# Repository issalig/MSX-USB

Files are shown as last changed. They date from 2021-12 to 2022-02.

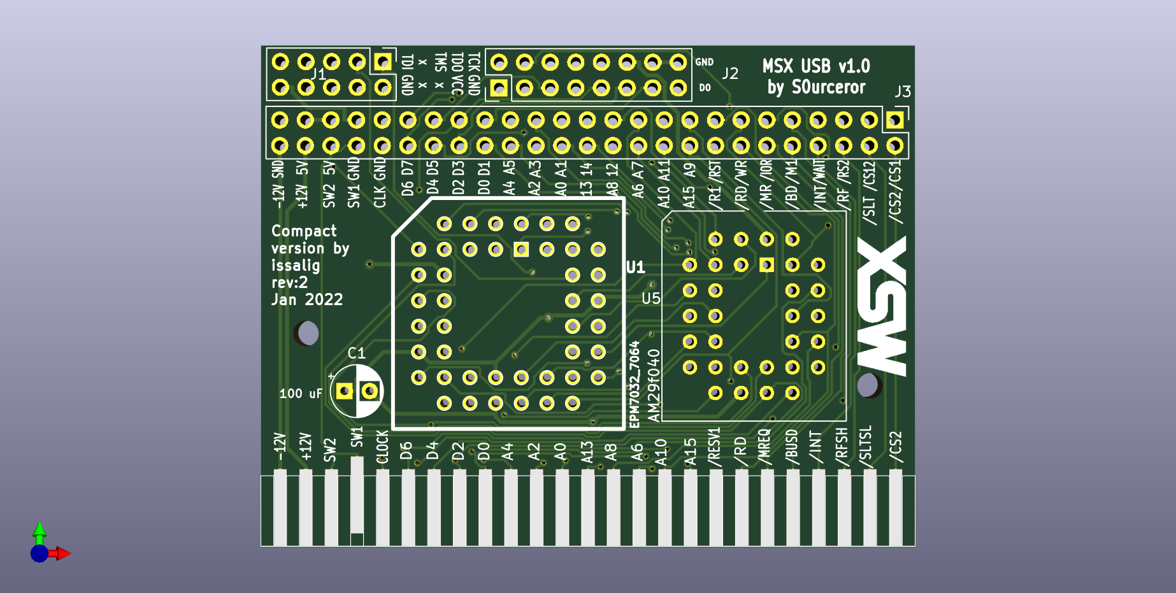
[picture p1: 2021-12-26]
hardware/kicad-cpld-mini-v2/MSX USB Drive.png

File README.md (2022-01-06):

# MSX-USB
## My fork and DIY guide
My fork provides a minified version of the pcb with PLC sockets and a header expansion as well as detailed building guide. All the other things are the same as original S0urceror version (https://github.com/S0urceror/MSX-USB) and I send him lots of thanks for sharing his knowledge.

As I built the cartridge from the scratch I will tell you some of the problems I faced and happily solved out.

### Step 0: Make a PCB
When I saw original S0urceror design I thought that maybe using PLC sockets could make the pcb smaller, then I tried to shrink everything into the minimum space with the maximum capabilities and that's why I added a expansion header. I am using https://www.kicad.org/ for the PCB layout and https://freerouting.org/ for the routing. I find freerouting extremely useful since there are a lot of connections and a small place to do the job. Sometines freerouting does not find the solution and you need to finish it manually. If this happens you can also lower clearance matrix values down to 125-150. Also using freerouting allows you to change the location of components without the need to re-route everything again.

Last version of the pcb is kicad-cpld-mini-v2 (ch376 is in front but still *untested*) and kicad-cpld-mini (ch376 is in the back side and *tested ok*).  Of course if you are satisfied with my design just can just use the files provided. Otherwise you can improve the design and share it.

### Step 1: Program CPLD
You will need the obsolete part EPM7064SLC44, the important part here is **SLC**, EPM7064SLC44-10 is also valid. You can get them from ali and other places but as they are refurbished/recovered from dumpsters expect to have only 50% working, so order double. Here is a possible link https://aliexpress.com/item/1005001512009032.html but there is a myriad of sellers.
Then, you will need a programmer such as USB blaster. I got this one https://aliexpress.com/item/1005002674193901.html
Next, you have to download Quartus software version **13.0sp1**, as newer versions do not support EPM7064. Go to https://fpgasoftware.intel.com/?edition=lite and proceed with the download and installation.

If you are in linux like me you will  need to add the this rules to file /etc/udev/rules.d/37-usbblaster.rules
```
SUBSYSTEM=="usb", ATTRS{idVendor}=="09fb", ATTRS{idProduct}=="6001", GROUP="plugdev", MODE="0666", SYMLINK+="usbblaster" 
```
and then restart the service
```
sudo service udev restart 
```

Connect the programmer to the board and also **power the board externally with 5V**, you can do it using the expansion header or CH3786 header. Find the pins VCC and GND and you are done. Failing to do so it will result in an JTAG read error.

Next, we check your connection and if everything went ok you will see this message.
```
$ ./quartus_pgm --auto
Info (213045): Using programming cable "USB-Blaster [3-1]"
1) USB-Blaster [3-1]
  070640DD   EPM7064S

Info: Quartus II 32-bit Programmer was successful. 0 errors, 0 warnings
    Info: Peak virtual memory: 127 megabytes
    Info: Processing ended: Sat Dec 18 10:16:56 2021
    Info: Elapsed time: 00:00:00
    Info: Total CPU time (on all processors): 00:00:00
```

And it has arrived the amazing moment where you are going to program it (you can do it with the command line *quartus_pgm* or with the GUI tool *quartus*)
with the following file https://github.com/S0urceror/MSX-USB/blob/master/hardware/quartus/output_files/MSXUSB.pof
```
./quartus_pgm -m jtag -o "p;./MSXUSB.pof"
```

In case the devices still shows JTAG communication error, keep calm and go to the next step.

### Step 1b. Recovering deaf JTAG units
It happens that some of the refurbished units come with programs that used JTAG pins for I/O and they are not able to be used for JTAG. I threw some of them to the bin until I discovered a recovery process (https://www.eevblog.com/forum/fpga/atmel-atf150x-cpld-and-wincupl/msg3162224/#msg3162224).
- Apply 12V to CPLD pin OE1 (44) with a 2k2 resistor for a minute or so. In my pcb you can access OE1 pin on header pin 15 (RST).
- Disconnect 12V, connect 5V and try to program it.
- Hopefully some CPLD's are working now! 

### Step 1c. Use an still in production CPLD, use a ATF1504AS
As seen in https://www.eevblog.com/forum/fpga/atmel-atf150x-cpld-and-wincupl/msg3113922/#msg3113922 ATF1504AS is pin compatible to EPM7064 and it is a valid replacement for EPM7064.
The changes are not that big: we will need to convert .pof into .jed and then into .svf.

I compiled the following info from different sources https://github.com/marqs85/snes_dejitter/blob/master/README.md, https://github.com/SukkoPera/OpenAmiga500FastRamExpansion/blob/master/firmware/README.md and https://www.hackup.net/2020/01/erasing-and-programming-the-atf1504-cpld/

All the resources for ATMEL CPLDS can be found at https://www.microchip.com/en-us/products/fpgas-and-plds/spld-cplds/pld-design-resources

First we need to download pof2jef from http://ww1.microchip.com/downloads/archive/pof2jed.zip
Then in winpof2jed.exe (yes it works with wine in linux :))
```
1. Select .pof file from previous step as input file
2. Select 1504AS as device
3. Change the following options:
  * Reduce MC power -> On
  * Open Collector -> Off
  * JTAG mode -> On
  * Slew rate -> Slow
4. Click "Run"
```

The important thing here is JTAG Mode **ON**, if you are wrong you will block JTAG but don't panic, we already know that applying 12V it will be enabled again.

Once we have the .jed file it is time to generate svf with ATMISP that you can download it from http://ww1.microchip.com/downloads/en/DeviceDoc/ATMISP7.zip. Then, you should follow these steps.

```
1. Create a new device chain via File->New
2. Set number of devices to 1
3. Set device to ATF1504AS
4. Set JTAG instruction to "Program/Verify"
5. Select .jed file from previous step as JEDEC file
6. Name your svf file
7. Click "OK"
8. Tick "Write SVF file" and click "Run"
```

We are almost there. We just need to flash it with openocd

But first we need the config file for usbblaster and you can save it as altera-usb-blaster.cfg
```
#
# Altera USB-Blaster
#
# http://www.altera.com/literature/ug/ug_usb_blstr.pdf
#

interface usb_blaster
usb_blaster_lowlevel_driver ftdi
# These are already the defaults.
# usb_blaster_vid_pid 0x09FB 0x6001
# usb_blaster_device_desc "USB-Blaster"
adapter_khz 3000
```

And this is the magical line that will flash your CPLD (Do not forget to power usbblaster with external 5V)

```
 openocd -f altera-usb-blaster.cfg -c "adapter_khz 400" -c "transport select jtag" -c "jtag newtap ATF1504AS tap -irlen 3 -expected-id 0x0150403f" -c init -c "svf msxusb.svf" -c "sleep 200" -c shutdown
 ```
 
If everything went ok you will see something ending like this

```
Time used: 0m12s613ms 
svf file programmed successfully for 3299 commands with 0 errors
shutdown command invoked

```

### Step 2. Flash memory
Recommended memory chips is SST39SF040 (512kb) but I also managed to make it work with SST39SF020 (256kb). Then, you will need a programmer such as TL866 II https://aliexpress.com/item/33000308958.html and the file we will write is located at https://github.com/S0urceror/MSX-USB/blob/master/drivers/NextorUsbHost/dist/nextor.rom

If you prefer to use a command line tool I suggest you minipro https://gitlab.com/DavidGriffith/minipro

```
$ ./minipro --device SST39SF040@PLCC32 --write nextor.rom -s
Found TL866II+ 04.2.126 (0x27e)
Warning: Firmware is newer than expected.
  Expected  04.2.124 (0x27c)
  Found     04.2.126 (0x27e)
Chip ID OK: 0xBFB7
Warning: Incorrect file size: 131072 (needed 524288)
Erasing... 0.40Sec OK
Writing Code...  26.38Sec  OK
Reading Code...  4.00Sec  OK
Verification OK

```

### Step 3. Select a valid USB drive
Not all USB drives will work :(, I have detected that the ones with the following EnpointAddress values usually work. It will probably work if you have the values shown below. If you find other values, please report.
```
lsusb -v | grep bEndpointAddress
...
bEndpointAddress 0x01 EP 1 OUT
bEndpointAddress 0x82 EP 2 IN 
```

### Step 4. Prepare a disk
Once we are here, all the hardware requirements are fulfilled, yes, you can go for a beer now!
It is only a matter of creating a disk image with the system files provided at https://github.com/S0urceror/MSX-USB/tree/master/software/dist

- If you have a MSX1 (i.e. VG8020, ...) you will be limited to 720kb disks and FAT12. Do not complain, do you still prefer a slow datacorder?
To create a MSX disk image I use dsktool from https://github.com/nataliapc/MSX_devs/tree/master/dsktool

I also provide linux and windows version of dsktool in order to make it easier, you can get them at https://github.com/issalig/MSX-USB/tree/master/software/utils
```
#create disk
dsktool c MYDISK.DSK
#add system files
dsktool a MYDISK.DSK COMMAND.COM MSXDOS.SYS
#add other files
dsktool a MYDISK.DSK MYGAME.COM
```
In case you prefer a GUI program you can also use DiskMgr http://www.lexlechz.at/en/software/DiskMgr.html

Next, flash it. **Warning: check if your device is /dev/sda** or you will destroy something. If you are a windows user maybe Rufus can write the image, if it works, please report it. 

```
sudo dd if=MYDISK.DSK of=/dev/sda
```

- If you are a lucky MSX2 owner you will need a FAT16 partition of 16Mb with COMMAND2.COM and NEXTOR.SYS.

In Linux I have created an image available at https://github.com/issalig/MSX-USB/blob/master/software/utils/msx2.zip. You can do it with the following commands.
```
#create a 16 Mb disk and format it to FAT16
sudo  dd if=/dev/zero of=msx2.dsk bs=1024 count=16k
sudo mkfs.fat -F 16 msx2.dsk

#mount it
mkdir 16mb 
sudo mount -o loop msx2.dsk 16mb/

#copy all the stuff
sudo cp COMMAND2.COM NEXTOR.SYS 16mb

#unmount it and flash it
sudo umount 16mb
sudo dd if=msx2.dsk of=/dev/sda bs=16M
```
Unplug the stick from the computer, plug it in the msxusb, switch on the MSX and you are in. **Enjoy!**

As usual report how is it done with windows (maybe mini partition tool can help but I have never tried it).

## Some history
In the 80's the MSX standard was created by Kazuhiko Nishi. He envisioned a simple yet powerful home computer based on standard hardware, software (BIOS/MSX DOS) and connectivity. From 1983 to 1990 manufacturers, like Philips, Sony, Yamaha, Sharp, Canon and many more, made computers according to this standard.

Because of the fact that extensibility was part of the standard people could design cartridges that would add synthesizer sound, memory, modems, rom-based games, or combinations of the above.

Cartridges were connected via a standard 50pin connector that remained the same accross 4 generations of MSX (1/2/2+/TurboR). BIOS and MSX-DOS were designed in a way to discover these via rom-based drivers, software hooks, extended bios.

Standardisation offers a big advantage because everything that adheres to the standard can connect to it.

## USB
USB was designed in the 90's to do something similar. To standardize the connection of peripherals to personal computers, both to communicate with and to supply electric power. It has now largely replaced interfaces such as serial ports and parallel ports, and has become commonplace on a wide range of devices. Like USB flash drives, keyboards, mice, wifi, serial, camera's, etc.

What if the MSX would have an USB connection? And if the BIOS/MSX DOS would automatically recognize devices connected to it?

## Meet MSX-USB
Inspired by the work of Xavirompe and his [RookieDrive](http://rookiedrive.com/en/) I set out to do exactly this. And since I'm a big believer of open standards and open source I'm opening up my work to everyone.

On this GitHub page you can find:
* Schematics (KiCAD), that interfaces a cheap USB CH376s board to the MSX cartridge port.
* Drivers, currently Flash drives on Nextor and HID keyboards are supported.
* Debugging tools, to connect a test board to your PC/MAC and assist in debugging.

On my GitHub I also have forks of OpenMSX and CocoaMSX that either emulate or connect to a test board via serial to assist in development and debugging.

## Schematics
This connects the CH376s board you can find on eBay or AliExpress for around 4 Euro to the MSX. 

Circuitry is added to correctly handle the _BUSDIR signal. Make sure you select parallel by setting the jumper on the CH376s board correctly.

The CH376s board will be visible on port 10h and 11h on the MSX. Port 11h is the command port and 10h is the data port. Specifics on how to program for the CH376s are scattered around the Internet:
* https://www.mpja.com/download/ch376ds1.pdf
* https://arduinobasics.blogspot.com/2015/05/ch376s-usb-readwrite-module.html

Most information is available on how to use the higher-order API for flash drives. 

If you want to use other USB devices you have to go low-level. As it turns out Konamiman already did some work there and after some researching I got USB HID Keyboards, Ethernet, Serial working as well. Check out my source-code or these great pages for more information:
* http://www.usbmadesimple.co.uk/index.html
* https://www.beyondlogic.org/usbnutshell/usb1.shtml

## UNAPI USB
I wrote a UNAPI USB specification and implemented the Usb Host driver according to this. The next version of this Host driver will also implement the Usb Hub specification and enumerate and initialise all devices connected.

## USB HID Keyboard
The Usb Keyboard driver connects to Unapi Usb driver and hooks itself to H.CHGE. From that moment on it replaces your trusted MSX keyboard by a shiny new USB Keyboard. Or a wireless one if you have inserted the appropriate Logitech receiver.

## USB CDC ECM Ethernet
The USB CDC ECM Ethernet driver is finished. It uses the Unapi USB and conforms to the Unapi Ethernet standard. Internestor Lite can now connect and use your USB Ethernet device. Please note that currently we only support USB CDC ECM. Make sure your Ethernet device supports this.

All USB Ethernet devices built around the **RTL8153** chipset support USB CDC ECM. They usually cost around 20 euro.

## USB Storage
A low level USB driver is created to connect to storage devices like thumb drives, portable hard disks, etc. 

## USB Hub
The USB Hub driver will interrogate an USB Hub and all devices connected to it.

# Installation instructions
Check [this page](INSTALL.md) for installation instructions and links to the various binaries that have been developed.

# Build your own (DIY)
Check [this page](DIY.md) for information on how to make the PCB, program the CPLD device, flash the ROM, etc.

# Collaboration
Do you want to help with the development of MSX USB? Write drivers for other devices? Or contribute in other ways?

Please drop me line on sourceror at neximus.nl or meet me on the msx.org forum.

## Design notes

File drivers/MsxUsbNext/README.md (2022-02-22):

## Usage
This is a Nextor driver programmed in C. It mounts the USB disk connected to the MSXUSB cartridge. Other devices and USB hubs are not supported by this driver.

### Disk formats supported
1. FAT32
    - Format in Windows, MacOS, Linux with master boot record. 
    - Place .DSK floppy images in the root folder or subfolders. 
    - Select the right DSK file during MSX boot.
2. FAT16
    - Format in Windows, MacOS, Linux with master boot record. 
    - Place .DSK floppy images in the root folder or subfolders. 
    - Select the right DSK file during MSX boot. 
    - **NEXTOR can also mount the whole USB drive in FAT16 mode**
3. FAT12
    - Format in MacOS, Linux or by DD-ing a DSK file to the USB drive. 
    - You will waste a lot of space because now the USB drive can only contain 720kb.

### MSX compatibility
On MSX 1 you can only mount FAT12 720kb DSK images. On MSX 2 and higher you can mount FAT16 DSK images of various sizes or the whole USB disk when formatted in FAT16.

### AUTOEXEC.DSK
Place a disk image called AUTOEXEC.DSK in the root of the USB drive to mount this image automatically. If your press ESCape within 3 seconds it will show the normal boot menu.

### CALL MOUNTDSK
In MSX Basic you can use the _MOUNTDSK or CALL MOUNTDSK command to show the boot menu again and change to another DSK image. Just like changing a floppy would.

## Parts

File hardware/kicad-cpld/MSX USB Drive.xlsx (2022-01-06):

/export
/@version | /components/comp/@ref | /components/comp/datasheet | /components/comp/footprint | /components/comp/libsource/@description | /components/comp/libsource/@lib | /components/comp/libsource/@part | /components/comp/sheetpath/@names | /components/comp/sheetpath/@tstamps | /components/comp/tstamp | /components/comp/value | /design/date | /design/sheet/@name | /design/sheet/@number | /design/sheet/@tstamps | /design/sheet/title_block/comment/@number | /design/sheet/title_block/comment/@value | /design/sheet/title_block/company | /design/sheet/title_block/date | /design/sheet/title_block/rev | /design/sheet/title_block/source | /design/sheet/title_block/title | /design/source | /design/tool | /libparts/libpart/@lib | /libparts/libpart/@part | /libparts/libpart/#id | /libparts/libpart/description | /libparts/libpart/docs | /libparts/libpart/fields/field/@name | /libparts/libpart/fields/field | /libparts/libpart/footprints/fp | /libparts/libpart/pins/pin/@name | /libparts/libpart/pins/pin/@num | /libparts/libpart/pins/pin/@type | /libraries/library/@logical | /libraries/library/uri | /nets/net/@code | /nets/net/@name | /nets/net/#id | /nets/net/node/@pin | /nets/net/node/@ref
D | C2 | ~ | Capacitor_SMD:C_0805_2012Metric_Pad1.15x1.40mm_HandSolder | Unpolarized capacitor | Device | C | / | / | 5E7F708E | 0.1 uF
D | C3 | ~ | Capacitor_SMD:C_0805_2012Metric_Pad1.15x1.40mm_HandSolder | Unpolarized capacitor | Device | C | / | / | 5E7FAB1D | 0.1 uF
D | C4 | ~ | Capacitor_SMD:C_0805_2012Metric_Pad1.15x1.40mm_HandSolder | Unpolarized capacitor | Device | C | / | / | 5E7FE759 | 0.1 uF
D | EDG1 |  | msx-usb-kicad-cpld:msx-con-MSXCART |  | msx-con | MSX_CON | / | / | 5E82E456 | MSX_CON
D | J2 | ~ | msx-usb-kicad-cpld:PinHeader_2x08_P2.54mm_Vertical | Generic connector, double row, 02x08, odd/even pin numbering scheme (row 1 odd numbers, row 2 even numbers), script generated (kicad-library-utils/schlib/autogen/connector/) | Connector_Generic | Conn_02x08_Odd_Even | / | / | 5D243AE7 | Conn_02x08_Odd_Even
D | U5 | http://ww1.microchip.com/downloads/en/DeviceDoc/25022B.pdf | msx-usb-kicad-cpld:DIP-32_W15.24mm_Socket | Silicon Storage Technology (SSF) 512k x 8 Flash ROM | Memory_Flash | SST39SF040 | / | / | 5DB86845 | AM29f040
D | U1 |  | msx-usb-kicad-cpld:PLCC44 |  | EPM7064_(44-PLCC) | EPM7032_7064 | / | / | 5E86BBA0 | EPM7032_7064
D | C1 | ~ | Capacitor_SMD:CP_Elec_6.3x5.4 | Unpolarized capacitor | Device | C | / | / | 5E84DCA7 | 100 uF
D | J1 | ~ | msx-usb-kicad-cpld:PinHeader_2x05_P2.54mm_Vertical | Atmel 10-pin JTAG connector | Connector | AVR-JTAG-10 | / | / | 5E822CA8 | AVR-JTAG-10
D |  |  |  |  |  |  |  |  |  |  | 2021 July 28, Wednesday 11:39:52 | / | 1 | / | 1 |  |  |  |  | MSX USB Drive.sch |  | /Users/mario/Development/msx/USB/hardware/kicad-cpld/MSX USB Drive.sch | Eeschema (5.1.7-0-10_14)
D |  |  |  |  |  |  |  |  |  |  | 2021 July 28, Wednesday 11:39:52 | / | 1 | / | 2 |  |  |  |  | MSX USB Drive.sch |  | /Users/mario/Development/msx/USB/hardware/kicad-cpld/MSX USB Drive.sch | Eeschema (5.1.7-0-10_14)
D |  |  |  |  |  |  |  |  |  |  | 2021 July 28, Wednesday 11:39:52 | / | 1 | / | 3 |  |  |  |  | MSX USB Drive.sch |  | /Users/mario/Development/msx/USB/hardware/kicad-cpld/MSX USB Drive.sch | Eeschema (5.1.7-0-10_14)
D |  |  |  |  |  |  |  |  |  |  | 2021 July 28, Wednesday 11:39:52 | / | 1 | / | 4 |  |  |  |  | MSX USB Drive.sch |  | /Users/mario/Development/msx/USB/hardware/kicad-cpld/MSX USB Drive.sch | Eeschema (5.1.7-0-10_14)
D |  |  |  |  |  |  |  |  |  |  |  |  |  |  |  |  |  |  |  |  |  |  |  | Connector | AVR-JTAG-10 | 1 | Atmel 10-pin JTAG connector | ~ | Reference | J
D |  |  |  |  |  |  |  |  |  |  |  |  |  |  |  |  |  |  |  |  |  |  |  | Connector | AVR-JTAG-10 | 1 | Atmel 10-pin JTAG connector | ~ | Value | AVR-JTAG-10
D |  |  |  |  |  |  |  |  |  |  |  |  |  |  |  |  |  |  |  |  |  |  |  | Connector | AVR-JTAG-10 | 1 | Atmel 10-pin JTAG connector | ~ |  |  | IDC?Header*2x05*
D |  |  |  |  |  |  |  |  |  |  |  |  |  |  |  |  |  |  |  |  |  |  |  | Connector | AVR-JTAG-10 | 1 | Atmel 10-pin JTAG connector | ~ |  |  | Pin?Header*2x05*
D |  |  |  |  |  |  |  |  |  |  |  |  |  |  |  |  |  |  |  |  |  |  |  | Connector | AVR-JTAG-10 | 1 | Atmel 10-pin JTAG connector | ~ |  |  |  | TCK | 1 | passive
D |  |  |  |  |  |  |  |  |  |  |  |  |  |  |  |  |  |  |  |  |  |  |  | Connector | AVR-JTAG-10 | 1 | Atmel 10-pin JTAG connector | ~ |  |  |  | GND | 2 | passive
D |  |  |  |  |  |  |  |  |  |  |  |  |  |  |  |  |  |  |  |  |  |  |  | Connector | AVR-JTAG-10 | 1 | Atmel 10-pin JTAG connector | ~ |  |  |  | TDO | 3 | passive
D |  |  |  |  |  |  |  |  |  |  |  |  |  |  |  |  |  |  |  |  |  |  |  | Connector | AVR-JTAG-10 | 1 | Atmel 10-pin JTAG connector | ~ |  |  |  | VREF | 4 | passive
D |  |  |  |  |  |  |  |  |  |  |  |  |  |  |  |  |  |  |  |  |  |  |  | Connector | AVR-JTAG-10 | 1 | Atmel 10-pin JTAG connector | ~ |  |  |  | TMS | 5 | passive
D |  |  |  |  |  |  |  |  |  |  |  |  |  |  |  |  |  |  |  |  |  |  |  | Connector | AVR-JTAG-10 | 1 | Atmel 10-pin JTAG connector | ~ |  |  |  | ~SRST | 6 | passive
D |  |  |  |  |  |  |  |  |  |  |  |  |  |  |  |  |  |  |  |  |  |  |  | Connector | AVR-JTAG-10 | 1 | Atmel 10-pin JTAG connector | ~ |  |  |  | VCC | 7 | passive
D |  |  |  |  |  |  |  |  |  |  |  |  |  |  |  |  |  |  |  |  |  |  |  | Connector | AVR-JTAG-10 | 1 | Atmel 10-pin JTAG connector | ~ |  |  |  | ~TRST | 8 | passive
D |  |  |  |  |  |  |  |  |  |  |  |  |  |  |  |  |  |  |  |  |  |  |  | Connector | AVR-JTAG-10 | 1 | Atmel 10-pin JTAG connector | ~ |  |  |  | TDI | 9 | passive
D |  |  |  |  |  |  |  |  |  |  |  |  |  |  |  |  |  |  |  |  |  |  |  | Connector | AVR-JTAG-10 | 1 | Atmel 10-pin JTAG connector | ~ |  |  |  | GND | 10 | passive
D |  |  |  |  |  |  |  |  |  |  |  |  |  |  |  |  |  |  |  |  |  |  |  | Connector_Generic | Conn_02x08_Odd_Even | 2 | Generic connector, double row, 02x08, odd/even pin numbering scheme (row 1 odd numbers, row 2 even numbers), script generated (kicad-library-utils/schlib/autogen/connector/) | ~ | Reference | J
D |  |  |  |  |  |  |  |  |  |  |  |  |  |  |  |  |  |  |  |  |  |  |  | Connector_Generic | Conn_02x08_Odd_Even | 2 | Generic connector, double row, 02x08, odd/even pin numbering scheme (row 1 odd numbers, row 2 even numbers), script generated (kicad-library-utils/schlib/autogen/connector/) | ~ | Value | Conn_02x08_Odd_Even
D |  |  |  |  |  |  |  |  |  |  |  |  |  |  |  |  |  |  |  |  |  |  |  | Connector_Generic | Conn_02x08_Odd_Even | 2 | Generic connector, double row, 02x08, odd/even pin numbering scheme (row 1 odd numbers, row 2 even numbers), script generated (kicad-library-utils/schlib/autogen/connector/) | ~ |  |  | Connector*:*_2x??_*
D |  |  |  |  |  |  |  |  |  |  |  |  |  |  |  |  |  |  |  |  |  |  |  | Connector_Generic | Conn_02x08_Odd_Even | 2 | Generic connector, double row, 02x08, odd/even pin numbering scheme (row 1 odd numbers, row 2 even numbers), script generated (kicad-library-utils/schlib/autogen/connector/) | ~ |  |  |  | Pin_1 | 1 | passive
D |  |  |  |  |  |  |  |  |  |  |  |  |  |  |  |  |  |  |  |  |  |  |  | Connector_Generic | Conn_02x08_Odd_Even | 2 | Generic connector, double row, 02x08, odd/even pin numbering scheme (row 1 odd numbers, row 2 even numbers), script generated (kicad-library-utils/schlib/autogen/connector/) | ~ |  |  |  | Pin_2 | 2 | passive
D |  |  |  |  |  |  |  |  |  |  |  |  |  |  |  |  |  |  |  |  |  |  |  | Connector_Generic | Conn_02x08_Odd_Even | 2 | Generic connector, double row, 02x08, odd/even pin numbering scheme (row 1 odd numbers, row 2 even numbers), script generated (kicad-library-utils/schlib/autogen/connector/) | ~ |  |  |  | Pin_3 | 3 | passive
D |  |  |  |  |  |  |  |  |  |  |  |  |  |  |  |  |  |  |  |  |  |  |  | Connector_Generic | Conn_02x08_Odd_Even | 2 | Generic connector, double row, 02x08, odd/even pin numbering scheme (row 1 odd numbers, row 2 even numbers), script generated (kicad-library-utils/schlib/autogen/connector/) | ~ |  |  |  | Pin_4 | 4 | passive
D |  |  |  |  |  |  |  |  |  |  |  |  |  |  |  |  |  |  |  |  |  |  |  | Connector_Generic | Conn_02x08_Odd_Even | 2 | Generic connector, double row, 02x08, odd/even pin numbering scheme (row 1 odd numbers, row 2 even numbers), script generated (kicad-library-utils/schlib/autogen/connector/) | ~ |  |  |  | Pin_5 | 5 | passive
D |  |  |  |  |  |  |  |  |  |  |  |  |  |  |  |  |  |  |  |  |  |  |  | Connector_Generic | Conn_02x08_Odd_Even | 2 | Generic connector, double row, 02x08, odd/even pin numbering scheme (row 1 odd numbers, row 2 even numbers), script generated (kicad-library-utils/schlib/autogen/connector/) | ~ |  |  |  | Pin_6 | 6 | passive
D |  |  |  |  |  |  |  |  |  |  |  |  |  |  |  |  |  |  |  |  |  |  |  | Connector_Generic | Conn_02x08_Odd_Even | 2 | Generic connector, double row, 02x08, odd/even pin numbering scheme (row 1 odd numbers, row 2 even numbers), script generated (kicad-library-utils/schlib/autogen/connector/) | ~ |  |  |  | Pin_7 | 7 | passive
D |  |  |  |  |  |  |  |  |  |  |  |  |  |  |  |  |  |  |  |  |  |  |  | Connector_Generic | Conn_02x08_Odd_Even | 2 | Generic connector, double row, 02x08, odd/even pin numbering scheme (row 1 odd numbers, row 2 even numbers), script generated (kicad-library-utils/schlib/autogen/connector/) | ~ |  |  |  | Pin_8 | 8 | passive
D |  |  |  |  |  |  |  |  |  |  |  |  |  |  |  |  |  |  |  |  |  |  |  | Connector_Generic | Conn_02x08_Odd_Even | 2 | Generic connector, double row, 02x08, odd/even pin numbering scheme (row 1 odd numbers, row 2 even numbers), script generated (kicad-library-utils/schlib/autogen/connector/) | ~ |  |  |  | Pin_9 | 9 | passive
D |  |  |  |  |  |  |  |  |  |  |  |  |  |  |  |  |  |  |  |  |  |  |  | Connector_Generic | Conn_02x08_Odd_Even | 2 | Generic connector, double row, 02x08, odd/even pin numbering scheme (row 1 odd numbers, row 2 even numbers), script generated (kicad-library-utils/schlib/autogen/connector/) | ~ |  |  |  | Pin_10 | 10 | passive
D |  |  |  |  |  |  |  |  |  |  |  |  |  |  |  |  |  |  |  |  |  |  |  | Connector_Generic | Conn_02x08_Odd_Even | 2 | Generic connector, double row, 02x08, odd/even pin numbering scheme (row 1 odd numbers, row 2 even numbers), script generated (kicad-library-utils/schlib/autogen/connector/) | ~ |  |  |  | Pin_11 | 11 | passive
D |  |  |  |  |  |  |  |  |  |  |  |  |  |  |  |  |  |  |  |  |  |  |  | Connector_Generic | Conn_02x08_Odd_Even | 2 | Generic connector, double row, 02x08, odd/even pin numbering scheme (row 1 odd numbers, row 2 even numbers), script generated (kicad-library-utils/schlib/autogen/connector/) | ~ |  |  |  | Pin_12 | 12 | passive
D |  |  |  |  |  |  |  |  |  |  |  |  |  |  |  |  |  |  |  |  |  |  |  | Connector_Generic | Conn_02x08_Odd_Even | 2 | Generic connector, double row, 02x08, odd/even pin numbering scheme (row 1 odd numbers, row 2 even numbers), script generated (kicad-library-utils/schlib/autogen/connector/) | ~ |  |  |  | Pin_13 | 13 | passive
D |  |  |  |  |  |  |  |  |  |  |  |  |  |  |  |  |  |  |  |  |  |  |  | Connector_Generic | Conn_02x08_Odd_Even | 2 | Generic connector, double row, 02x08, odd/even pin numbering scheme (row 1 odd numbers, row 2 even numbers), script generated (kicad-library-utils/schlib/autogen/connector/) | ~ |  |  |  | Pin_14 | 14 | passive
D |  |  |  |  |  |  |  |  |  |  |  |  |  |  |  |  |  |  |  |  |  |  |  | Connector_Generic | Conn_02x08_Odd_Even | 2 | Generic connector, double row, 02x08, odd/even pin numbering scheme (row 1 odd numbers, row 2 even numbers), script generated (kicad-library-utils/schlib/autogen/connector/) | ~ |  |  |  | Pin_15 | 15 | passive
D |  |  |  |  |  |  |  |  |  |  |  |  |  |  |  |  |  |  |  |  |  |  |  | Connector_Generic | Conn_02x08_Odd_Even | 2 | Generic connector, double row, 02x08, odd/even pin numbering scheme (row 1 odd numbers, row 2 even numbers), script generated (kicad-library-utils/schlib/autogen/connector/) | ~ |  |  |  | Pin_16 | 16 | passive
D |  |  |  |  |  |  |  |  |  |  |  |  |  |  |  |  |  |  |  |  |  |  |  | Device | C | 3 | Unpolarized capacitor | ~ | Reference | C
D |  |  |  |  |  |  |  |  |  |  |  |  |  |  |  |  |  |  |  |  |  |  |  | Device | C | 3 | Unpolarized capacitor | ~ | Value | C
D |  |  |  |  |  |  |  |  |  |  |  |  |  |  |  |  |  |  |  |  |  |  |  | Device | C | 3 | Unpolarized capacitor | ~ |  |  | C_*
D |  |  |  |  |  |  |  |  |  |  |  |  |  |  |  |  |  |  |  |  |  |  |  | Device | C | 3 | Unpolarized capacitor | ~ |  |  |  | ~ | 1 | passive
D |  |  |  |  |  |  |  |  |  |  |  |  |  |  |  |  |  |  |  |  |  |  |  | Device | C | 3 | Unpolarized capacitor | ~ |  |  |  | ~ | 2 | passive
D |  |  |  |  |  |  |  |  |  |  |  |  |  |  |  |  |  |  |  |  |  |  |  | EPM7064_(44-PLCC) | EPM7032_7064 | 4 |  |  | Reference | U
D |  |  |  |  |  |  |  |  |  |  |  |  |  |  |  |  |  |  |  |  |  |  |  | EPM7064_(44-PLCC) | EPM7032_7064 | 4 |  |  | Value | EPM7032_7064
D |  |  |  |  |  |  |  |  |  |  |  |  |  |  |  |  |  |  |  |  |  |  |  | EPM7064_(44-PLCC) | EPM7032_7064 | 4 |  |  |  |  |  | GCLRn | 1 | BiDi
D |  |  |  |  |  |  |  |  |  |  |  |  |  |  |  |  |  |  |  |  |  |  |  | EPM7064_(44-PLCC) | EPM7032_7064 | 4 |  |  |  |  |  | GCLK1 | 2 | BiDi
D |  |  |  |  |  |  |  |  |  |  |  |  |  |  |  |  |  |  |  |  |  |  |  | EPM7064_(44-PLCC) | EPM7032_7064 | 4 |  |  |  |  |  | VCC | 3 | power_in
D |  |  |  |  |  |  |  |  |  |  |  |  |  |  |  |  |  |  |  |  |  |  |  | EPM7064_(44-PLCC) | EPM7032_7064 | 4 |  |  |  |  |  | I/O | 4 | BiDi
D |  |  |  |  |  |  |  |  |  |  |  |  |  |  |  |  |  |  |  |  |  |  |  | EPM7064_(44-PLCC) | EPM7032_7064 | 4 |  |  |  |  |  | I/O | 5 | BiDi
D |  |  |  |  |  |  |  |  |  |  |  |  |  |  |  |  |  |  |  |  |  |  |  | EPM7064_(44-PLCC) | EPM7032_7064 | 4 |  |  |  |  |  | I/O | 6 | BiDi
D |  |  |  |  |  |  |  |  |  |  |  |  |  |  |  |  |  |  |  |  |  |  |  | EPM7064_(44-PLCC) | EPM7032_7064 | 4 |  |  |  |  |  | TDI | 7 | input
D |  |  |  |  |  |  |  |  |  |  |  |  |  |  |  |  |  |  |  |  |  |  |  | EPM7064_(44-PLCC) | EPM7032_7064 | 4 |  |  |  |  |  | I/O | 8 | BiDi
D |  |  |  |  |  |  |  |  |  |  |  |  |  |  |  |  |  |  |  |  |  |  |  | EPM7064_(44-PLCC) | EPM7032_7064 | 4 |  |  |  |  |  | I/O | 9 | BiDi
D |  |  |  |  |  |  |  |  |  |  |  |  |  |  |  |  |  |  |  |  |  |  |  | EPM7064_(44-PLCC) | EPM7032_7064 | 4 |  |  |  |  |  | GND | 10 | power_in
D |  |  |  |  |  |  |  |  |  |  |  |  |  |  |  |  |  |  |  |  |  |  |  | EPM7064_(44-PLCC) | EPM7032_7064 | 4 |  |  |  |  |  | I/O | 11 | BiDi
D |  |  |  |  |  |  |  |  |  |  |  |  |  |  |  |  |  |  |  |  |  |  |  | EPM7064_(44-PLCC) | EPM7032_7064 | 4 |  |  |  |  |  | I/O | 12 | BiDi
D |  |  |  |  |  |  |  |  |  |  |  |  |  |  |  |  |  |  |  |  |  |  |  | EPM7064_(44-PLCC) | EPM7032_7064 | 4 |  |  |  |  |  | TMS | 13 | input
D |  |  |  |  |  |  |  |  |  |  |  |  |  |  |  |  |  |  |  |  |  |  |  | EPM7064_(44-PLCC) | EPM7032_7064 | 4 |  |  |  |  |  | I/O | 14 | BiDi
D |  |  |  |  |  |  |  |  |  |  |  |  |  |  |  |  |  |  |  |  |  |  |  | EPM7064_(44-PLCC) | EPM7032_7064 | 4 |  |  |  |  |  | VCC | 15 | power_in
D |  |  |  |  |  |  |  |  |  |  |  |  |  |  |  |  |  |  |  |  |  |  |  | EPM7064_(44-PLCC) | EPM7032_7064 | 4 |  |  |  |  |  | I/O | 16 | BiDi
D |  |  |  |  |  |  |  |  |  |  |  |  |  |  |  |  |  |  |  |  |  |  |  | EPM7064_(44-PLCC) | EPM7032_7064 | 4 |  |  |  |  |  | I/O | 17 | BiDi
D |  |  |  |  |  |  |  |  |  |  |  |  |  |  |  |  |  |  |  |  |  |  |  | EPM7064_(44-PLCC) | EPM7032_7064 | 4 |  |  |  |  |  | I/O | 18 | BiDi
D |  |  |  |  |  |  |  |  |  |  |  |  |  |  |  |  |  |  |  |  |  |  |  | EPM7064_(44-PLCC) | EPM7032_7064 | 4 |  |  |  |  |  | I/O | 19 | BiDi
D |  |  |  |  |  |  |  |  |  |  |  |  |  |  |  |  |  |  |  |  |  |  |  | EPM7064_(44-PLCC) | EPM7032_7064 | 4 |  |  |  |  |  | I/O | 20 | BiDi
D |  |  |  |  |  |  |  |  |  |  |  |  |  |  |  |  |  |  |  |  |  |  |  | EPM7064_(44-PLCC) | EPM7032_7064 | 4 |  |  |  |  |  | I/O | 21 | BiDi
D |  |  |  |  |  |  |  |  |  |  |  |  |  |  |  |  |  |  |  |  |  |  |  | EPM7064_(44-PLCC) | EPM7032_7064 | 4 |  |  |  |  |  | GND | 22 | power_in
D |  |  |  |  |  |  |  |  |  |  |  |  |  |  |  |  |  |  |  |  |  |  |  | EPM7064_(44-PLCC) | EPM7032_7064 | 4 |  |  |  |  |  | VCC | 23 | power_in
D |  |  |  |  |  |  |  |  |  |  |  |  |  |  |  |  |  |  |  |  |  |  |  | EPM7064_(44-PLCC) | EPM7032_7064 | 4 |  |  |  |  |  | I/O | 24 | BiDi
D |  |  |  |  |  |  |  |  |  |  |  |  |  |  |  |  |  |  |  |  |  |  |  | EPM7064_(44-PLCC) | EPM7032_7064 | 4 |  |  |  |  |  | I/O | 25 | BiDi
D |  |  |  |  |  |  |  |  |  |  |  |  |  |  |  |  |  |  |  |  |  |  |  | EPM7064_(44-PLCC) | EPM7032_7064 | 4 |  |  |  |  |  | I/O | 26 | BiDi
D |  |  |  |  |  |  |  |  |  |  |  |  |  |  |  |  |  |  |  |  |  |  |  | EPM7064_(44-PLCC) | EPM7032_7064 | 4 |  |  |  |  |  | I/O | 27 | BiDi
D |  |  |  |  |  |  |  |  |  |  |  |  |  |  |  |  |  |  |  |  |  |  |  | EPM7064_(44-PLCC) | EPM7032_7064 | 4 |  |  |  |  |  | I/O | 28 | BiDi
D |  |  |  |  |  |  |  |  |  |  |  |  |  |  |  |  |  |  |  |  |  |  |  | EPM7064_(44-PLCC) | EPM7032_7064 | 4 |  |  |  |  |  | I/O | 29 | BiDi
D |  |  |  |  |  |  |  |  |  |  |  |  |  |  |  |  |  |  |  |  |  |  |  | EPM7064_(44-PLCC) | EPM7032_7064 | 4 |  |  |  |  |  | GND | 30 | power_in
D |  |  |  |  |  |  |  |  |  |  |  |  |  |  |  |  |  |  |  |  |  |  |  | EPM7064_(44-PLCC) | EPM7032_7064 | 4 |  |  |  |  |  | I/O | 31 | BiDi
D |  |  |  |  |  |  |  |  |  |  |  |  |  |  |  |  |  |  |  |  |  |  |  | EPM7064_(44-PLCC) | EPM7032_7064 | 4 |  |  |  |  |  | TCK | 32 | input
D |  |  |  |  |  |  |  |  |  |  |  |  |  |  |  |  |  |  |  |  |  |  |  | EPM7064_(44-PLCC) | EPM7032_7064 | 4 |  |  |  |  |  | I/O | 33 | BiDi
D |  |  |  |  |  |  |  |  |  |  |  |  |  |  |  |  |  |  |  |  |  |  |  | EPM7064_(44-PLCC) | EPM7032_7064 | 4 |  |  |  |  |  | I/O | 34 | BiDi
D |  |  |  |  |  |  |  |  |  |  |  |  |  |  |  |  |  |  |  |  |  |  |  | EPM7064_(44-PLCC) | EPM7032_7064 | 4 |  |  |  |  |  | VCC | 35 | power_in
D |  |  |  |  |  |  |  |  |  |  |  |  |  |  |  |  |  |  |  |  |  |  |  | EPM7064_(44-PLCC) | EPM7032_7064 | 4 |  |  |  |  |  | I/O | 36 | BiDi
D |  |  |  |  |  |  |  |  |  |  |  |  |  |  |  |  |  |  |  |  |  |  |  | EPM7064_(44-PLCC) | EPM7032_7064 | 4 |  |  |  |  |  | I/O | 37 | BiDi
D |  |  |  |  |  |  |  |  |  |  |  |  |  |  |  |  |  |  |  |  |  |  |  | EPM7064_(44-PLCC) | EPM7032_7064 | 4 |  |  |  |  |  | TDO | 38 | BiDi
D |  |  |  |  |  |  |  |  |  |  |  |  |  |  |  |  |  |  |  |  |  |  |  | EPM7064_(44-PLCC) | EPM7032_7064 | 4 |  |  |  |  |  | I/O | 39 | BiDi
D |  |  |  |  |  |  |  |  |  |  |  |  |  |  |  |  |  |  |  |  |  |  |  | EPM7064_(44-PLCC) | EPM7032_7064 | 4 |  |  |  |  |  | I/O | 40 | BiDi
D |  |  |  |  |  |  |  |  |  |  |  |  |  |  |  |  |  |  |  |  |  |  |  | EPM7064_(44-PLCC) | EPM7032_7064 | 4 |  |  |  |  |  | I/O | 41 | BiDi
D |  |  |  |  |  |  |  |  |  |  |  |  |  |  |  |  |  |  |  |  |  |  |  | EPM7064_(44-PLCC) | EPM7032_7064 | 4 |  |  |  |  |  | GND | 42 | power_in
D |  |  |  |  |  |  |  |  |  |  |  |  |  |  |  |  |  |  |  |  |  |  |  | EPM7064_(44-PLCC) | EPM7032_7064 | 4 |  |  |  |  |  | GCLK1 | 43 | BiDi
D |  |  |  |  |  |  |  |  |  |  |  |  |  |  |  |  |  |  |  |  |  |  |  | EPM7064_(44-PLCC) | EPM7032_7064 | 4 |  |  |  |  |  | OE1 | 44 | BiDi
D |  |  |  |  |  |  |  |  |  |  |  |  |  |  |  |  |  |  |  |  |  |  |  | Memory_Flash | SST39SF040 | 5 | Silicon Storage Technology (SSF) 512k x 8 Flash ROM | http://ww1.microchip.com/downloads/en/DeviceDoc/25022B.pdf | Reference | U
D |  |  |  |  |  |  |  |  |  |  |  |  |  |  |  |  |  |  |  |  |  |  |  | Memory_Flash | SST39SF040 | 5 | Silicon Storage Technology (SSF) 512k x 8 Flash ROM | http://ww1.microchip.com/downloads/en/DeviceDoc/25022B.pdf | Value | SST39SF040
D |  |  |  |  |  |  |  |  |  |  |  |  |  |  |  |  |  |  |  |  |  |  |  | Memory_Flash | SST39SF040 | 5 | Silicon Storage Technology (SSF) 512k x 8 Flash ROM | http://ww1.microchip.com/downloads/en/DeviceDoc/25022B.pdf |  |  |  | A18 | 1 | input
D |  |  |  |  |  |  |  |  |  |  |  |  |  |  |  |  |  |  |  |  |  |  |  | Memory_Flash | SST39SF040 | 5 | Silicon Storage Technology (SSF) 512k x 8 Flash ROM | http://ww1.microchip.com/downloads/en/DeviceDoc/25022B.pdf |  |  |  | A16 | 2 | input
D |  |  |  |  |  |  |  |  |  |  |  |  |  |  |  |  |  |  |  |  |  |  |  | Memory_Flash | SST39SF040 | 5 | Silicon Storage Technology (SSF) 512k x 8 Flash ROM | http://ww1.microchip.com/downloads/en/DeviceDoc/25022B.pdf |  |  |  | A15 | 3 | input
D |  |  |  |  |  |  |  |  |  |  |  |  |  |  |  |  |  |  |  |  |  |  |  | Memory_Flash | SST39SF040 | 5 | Silicon Storage Technology (SSF) 512k x 8 Flash ROM | http://ww1.microchip.com/downloads/en/DeviceDoc/25022B.pdf |  |  |  | A12 | 4 | input
D |  |  |  |  |  |  |  |  |  |  |  |  |  |  |  |  |  |  |  |  |  |  |  | Memory_Flash | SST39SF040 | 5 | Silicon Storage Technology (SSF) 512k x 8 Flash ROM | http://ww1.microchip.com/downloads/en/DeviceDoc/25022B.pdf |  |  |  | A7 | 5 | input
D |  |  |  |  |  |  |  |  |  |  |  |  |  |  |  |  |  |  |  |  |  |  |  | Memory_Flash | SST39SF040 | 5 | Silicon Storage Technology (SSF) 512k x 8 Flash ROM | http://ww1.microchip.com/downloads/en/DeviceDoc/25022B.pdf |  |  |  | A6 | 6 | input
D |  |  |  |  |  |  |  |  |  |  |  |  |  |  |  |  |  |  |  |  |  |  |  | Memory_Flash | SST39SF040 | 5 | Silicon Storage Technology (SSF) 512k x 8 Flash ROM | http://ww1.microchip.com/downloads/en/DeviceDoc/25022B.pdf |  |  |  | A5 | 7 | input
D |  |  |  |  |  |  |  |  |  |  |  |  |  |  |  |  |  |  |  |  |  |  |  | Memory_Flash | SST39SF040 | 5 | Silicon Storage Technology (SSF) 512k x 8 Flash ROM | http://ww1.microchip.com/downloads/en/DeviceDoc/25022B.pdf |  |  |  | A4 | 8 | input
D |  |  |  |  |  |  |  |  |  |  |  |  |  |  |  |  |  |  |  |  |  |  |  | Memory_Flash | SST39SF040 | 5 | Silicon Storage Technology (SSF) 512k x 8 Flash ROM | http://ww1.microchip.com/downloads/en/DeviceDoc/25022B.pdf |  |  |  | A3 | 9 | input
D |  |  |  |  |  |  |  |  |  |  |  |  |  |  |  |  |  |  |  |  |  |  |  | Memory_Flash | SST39SF040 | 5 | Silicon Storage Technology (SSF) 512k x 8 Flash ROM | http://ww1.microchip.com/downloads/en/DeviceDoc/25022B.pdf |  |  |  | A2 | 10 | input
D |  |  |  |  |  |  |  |  |  |  |  |  |  |  |  |  |  |  |  |  |  |  |  | Memory_Flash | SST39SF040 | 5 | Silicon Storage Technology (SSF) 512k x 8 Flash ROM | http://ww1.microchip.com/downloads/en/DeviceDoc/25022B.pdf |  |  |  | A1 | 11 | input
D |  |  |  |  |  |  |  |  |  |  |  |  |  |  |  |  |  |  |  |  |  |  |  | Memory_Flash | SST39SF040 | 5 | Silicon Storage Technology (SSF) 512k x 8 Flash ROM | http://ww1.microchip.com/downloads/en/DeviceDoc/25022B.pdf |  |  |  | A0 | 12 | input
D |  |  |  |  |  |  |  |  |  |  |  |  |  |  |  |  |  |  |  |  |  |  |  | Memory_Flash | SST39SF040 | 5 | Silicon Storage Technology (SSF) 512k x 8 Flash ROM | http://ww1.microchip.com/downloads/en/DeviceDoc/25022B.pdf |  |  |  | D0 | 13 | 3state
D |  |  |  |  |  |  |  |  |  |  |  |  |  |  |  |  |  |  |  |  |  |  |  | Memory_Flash | SST39SF040 | 5 | Silicon Storage Technology (SSF) 512k x 8 Flash ROM | http://ww1.microchip.com/downloads/en/DeviceDoc/25022B.pdf |  |  |  | D1 | 14 | 3state
D |  |  |  |  |  |  |  |  |  |  |  |  |  |  |  |  |  |  |  |  |  |  |  | Memory_Flash | SST39SF040 | 5 | Silicon Storage Technology (SSF) 512k x 8 Flash ROM | http://ww1.microchip.com/downloads/en/DeviceDoc/25022B.pdf |  |  |  | D2 | 15 | 3state
D |  |  |  |  |  |  |  |  |  |  |  |  |  |  |  |  |  |  |  |  |  |  |  | Memory_Flash | SST39SF040 | 5 | Silicon Storage Technology (SSF) 512k x 8 Flash ROM | http://ww1.microchip.com/downloads/en/DeviceDoc/25022B.pdf |  |  |  | GND | 16 | power_in
D |  |  |  |  |  |  |  |  |  |  |  |  |  |  |  |  |  |  |  |  |  |  |  | Memory_Flash | SST39SF040 | 5 | Silicon Storage Technology (SSF) 512k x 8 Flash ROM | http://ww1.microchip.com/downloads/en/DeviceDoc/25022B.pdf |  |  |  | D3 | 17 | 3state
D |  |  |  |  |  |  |  |  |  |  |  |  |  |  |  |  |  |  |  |  |  |  |  | Memory_Flash | SST39SF040 | 5 | Silicon Storage Technology (SSF) 512k x 8 Flash ROM | http://ww1.microchip.com/downloads/en/DeviceDoc/25022B.pdf |  |  |  | D4 | 18 | 3state
D |  |  |  |  |  |  |  |  |  |  |  |  |  |  |  |  |  |  |  |  |  |  |  | Memory_Flash | SST39SF040 | 5 | Silicon Storage Technology (SSF) 512k x 8 Flash ROM | http://ww1.microchip.com/downloads/en/DeviceDoc/25022B.pdf |  |  |  | D5 | 19 | 3state
D |  |  |  |  |  |  |  |  |  |  |  |  |  |  |  |  |  |  |  |  |  |  |  | Memory_Flash | SST39SF040 | 5 | Silicon Storage Technology (SSF) 512k x 8 Flash ROM | http://ww1.microchip.com/downloads/en/DeviceDoc/25022B.pdf |  |  |  | D6 | 20 | 3state
D |  |  |  |  |  |  |  |  |  |  |  |  |  |  |  |  |  |  |  |  |  |  |  | Memory_Flash | SST39SF040 | 5 | Silicon Storage Technology (SSF) 512k x 8 Flash ROM | http://ww1.microchip.com/downloads/en/DeviceDoc/25022B.pdf |  |  |  | D7 | 21 | 3state
D |  |  |  |  |  |  |  |  |  |  |  |  |  |  |  |  |  |  |  |  |  |  |  | Memory_Flash | SST39SF040 | 5 | Silicon Storage Technology (SSF) 512k x 8 Flash ROM | http://ww1.microchip.com/downloads/en/DeviceDoc/25022B.pdf |  |  |  | CE | 22 | input
D |  |  |  |  |  |  |  |  |  |  |  |  |  |  |  |  |  |  |  |  |  |  |  | Memory_Flash | SST39SF040 | 5 | Silicon Storage Technology (SSF) 512k x 8 Flash ROM | http://ww1.microchip.com/downloads/en/DeviceDoc/25022B.pdf |  |  |  | A10 | 23 | input
D |  |  |  |  |  |  |  |  |  |  |  |  |  |  |  |  |  |  |  |  |  |  |  | Memory_Flash | SST39SF040 | 5 | Silicon Storage Technology (SSF) 512k x 8 Flash ROM | http://ww1.microchip.com/downloads/en/DeviceDoc/25022B.pdf |  |  |  | OE | 24 | input
D |  |  |  |  |  |  |  |  |  |  |  |  |  |  |  |  |  |  |  |  |  |  |  | Memory_Flash | SST39SF040 | 5 | Silicon Storage Technology (SSF) 512k x 8 Flash ROM | http://ww1.microchip.com/downloads/en/DeviceDoc/25022B.pdf |  |  |  | A11 | 25 | input
D |  |  |  |  |  |  |  |  |  |  |  |  |  |  |  |  |  |  |  |  |  |  |  | Memory_Flash | SST39SF040 | 5 | Silicon Storage Technology (SSF) 512k x 8 Flash ROM | http://ww1.microchip.com/downloads/en/DeviceDoc/25022B.pdf |  |  |  | A9 | 26 | input
D |  |  |  |  |  |  |  |  |  |  |  |  |  |  |  |  |  |  |  |  |  |  |  | Memory_Flash | SST39SF040 | 5 | Silicon Storage Technology (SSF) 512k x 8 Flash ROM | http://ww1.microchip.com/downloads/en/DeviceDoc/25022B.pdf |  |  |  | A8 | 27 | input
D |  |  |  |  |  |  |  |  |  |  |  |  |  |  |  |  |  |  |  |  |  |  |  | Memory_Flash | SST39SF040 | 5 | Silicon Storage Technology (SSF) 512k x 8 Flash ROM | http://ww1.microchip.com/downloads/en/DeviceDoc/25022B.pdf |  |  |  | A13 | 28 | input
D |  |  |  |  |  |  |  |  |  |  |  |  |  |  |  |  |  |  |  |  |  |  |  | Memory_Flash | SST39SF040 | 5 | Silicon Storage Technology (SSF) 512k x 8 Flash ROM | http://ww1.microchip.com/downloads/en/DeviceDoc/25022B.pdf |  |  |  | A14 | 29 | input
D |  |  |  |  |  |  |  |  |  |  |  |  |  |  |  |  |  |  |  |  |  |  |  | Memory_Flash | SST39SF040 | 5 | Silicon Storage Technology (SSF) 512k x 8 Flash ROM | http://ww1.microchip.com/downloads/en/DeviceDoc/25022B.pdf |  |  |  | A17 | 30 | input
D |  |  |  |  |  |  |  |  |  |  |  |  |  |  |  |  |  |  |  |  |  |  |  | Memory_Flash | SST39SF040 | 5 | Silicon Storage Technology (SSF) 512k x 8 Flash ROM | http://ww1.microchip.com/downloads/en/DeviceDoc/25022B.pdf |  |  |  | PGM | 31 | input
D |  |  |  |  |  |  |  |  |  |  |  |  |  |  |  |  |  |  |  |  |  |  |  | Memory_Flash | SST39SF040 | 5 | Silicon Storage Technology (SSF) 512k x 8 Flash ROM | http://ww1.microchip.com/downloads/en/DeviceDoc/25022B.pdf |  |  |  | VCC | 32 | power_in
D |  |  |  |  |  |  |  |  |  |  |  |  |  |  |  |  |  |  |  |  |  |  |  | msx-con | MSX_CON | 6 |  |  | Reference | EDG
D |  |  |  |  |  |  |  |  |  |  |  |  |  |  |  |  |  |  |  |  |  |  |  | msx-con | MSX_CON | 6 |  |  | Value | MSX_CON
D |  |  |  |  |  |  |  |  |  |  |  |  |  |  |  |  |  |  |  |  |  |  |  | msx-con | MSX_CON | 6 |  |  | Footprint | msx-con_MSX_CON
D |  |  |  |  |  |  |  |  |  |  |  |  |  |  |  |  |  |  |  |  |  |  |  | msx-con | MSX_CON | 6 |  |  |  |  | *MSX_CON*
D |  |  |  |  |  |  |  |  |  |  |  |  |  |  |  |  |  |  |  |  |  |  |  | msx-con | MSX_CON | 6 |  |  |  |  |  | +12V | +12V | power_out
D |  |  |  |  |  |  |  |  |  |  |  |  |  |  |  |  |  |  |  |  |  |  |  | msx-con | MSX_CON | 6 |  |  |  |  |  | +5V | +5V1 | power_out
D |  |  |  |  |  |  |  |  |  |  |  |  |  |  |  |  |  |  |  |  |  |  |  | msx-con | MSX_CON | 6 |  |  |  |  |  | +5V | +5V2 | power_out
D |  |  |  |  |  |  |  |  |  |  |  |  |  |  |  |  |  |  |  |  |  |  |  | msx-con | MSX_CON | 6 |  |  |  |  |  | -12V | -12V | power_out
D |  |  |  |  |  |  |  |  |  |  |  |  |  |  |  |  |  |  |  |  |  |  |  | msx-con | MSX_CON | 6 |  |  |  |  |  | ~BUSDIR | /BUSDIR | input
D |  |  |  |  |  |  |  |  |  |  |  |  |  |  |  |  |  |  |  |  |  |  |  | msx-con | MSX_CON | 6 |  |  |  |  |  | ~CS1 | /CS1 | output
D |  |  |  |  |  |  |  |  |  |  |  |  |  |  |  |  |  |  |  |  |  |  |  | msx-con | MSX_CON | 6 |  |  |  |  |  | ~CS2 | /CS2 | output
D |  |  |  |  |  |  |  |  |  |  |  |  |  |  |  |  |  |  |  |  |  |  |  | msx-con | MSX_CON | 6 |  |  |  |  |  | ~CS12 | /CS12 | output
D |  |  |  |  |  |  |  |  |  |  |  |  |  |  |  |  |  |  |  |  |  |  |  | msx-con | MSX_CON | 6 |  |  |  |  |  | ~INT | /INT | input
D |  |  |  |  |  |  |  |  |  |  |  |  |  |  |  |  |  |  |  |  |  |  |  | msx-con | MSX_CON | 6 |  |  |  |  |  | ~IORQ | /IORQ | output
D |  |  |  |  |  |  |  |  |  |  |  |  |  |  |  |  |  |  |  |  |  |  |  | msx-con | MSX_CON | 6 |  |  |  |  |  | ~M1 | /M1 | output
D |  |  |  |  |  |  |  |  |  |  |  |  |  |  |  |  |  |  |  |  |  |  |  | msx-con | MSX_CON | 6 |  |  |  |  |  | ~MERQ | /MREQ | output
D |  |  |  |  |  |  |  |  |  |  |  |  |  |  |  |  |  |  |  |  |  |  |  | msx-con | MSX_CON | 6 |  |  |  |  |  | ~RD | /RD | output
D |  |  |  |  |  |  |  |  |  |  |  |  |  |  |  |  |  |  |  |  |  |  |  | msx-con | MSX_CON | 6 |  |  |  |  |  | ~RESET | /RESET | output
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

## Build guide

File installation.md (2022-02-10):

# Setting up the development environment
It is possible and more than recommendable to use openMSX for development and testing. Thus, you do not need to flash roms and you can try it on different machines. For this task you will also need and arduino UNO or similar which will be the bridge between PC and CH376s (ESP8266 will not work, because it has not enough pins but ESP32 should do, any volunteer? )

# Compiling rom
In this section I will focus on the MsxUsbNext rom but this is not a problem because requirements for other roms will be almost the same. Code is located at https://github.com/S0urceror/MSX-USB/tree/master/drivers/MsxUsbNext/macos

MsxUsbNext has several parts, macos which is a version to test from the computer (it is also valid for linux and maybe for windows with cygwin but not wsl2 which does not support usbs afaik), and msx which is the version that we will flash on the cartridge, ie., the rom.

First, you will need to install g++, clang, sjasm, and sdcc.
```
sudo apt-get install g++ clang sjasm sdcc
```
hex2bin is also necessary and you can get it from https://github.com/ericb59/Fusion-C-v1.2/tree/master/Working%20Folder/Tools/Hex2bin-2.5

Also you will need mknexrom. The one provided is for MacOS but if you are not in MacOS, just build or download mknexrom from https://github.com/Konamiman/Nextor/blob/v2.1/buildtools/linux/mknexrom and copy it to https://github.com/S0urceror/MSX-USB/tree/master/drivers/MsxUsbNext/msx/kernel 

Once here, you should have all the required tools in order to build the rom.

Now, go to macos directory, create a build dir and make it!
```
cd macos
mkdir build
make
```
Take into account that you will probably need to edit ```hal.c``` file and set your usb device name. For example: ```char device[] = "/dev/ttyUSB0";```.

The built executable performs the same operations that will be done in rom but allows you to test it in a more confortable environment.

# Arduino
The skecth needed is found at https://github.com/S0urceror/MSX-USB/blob/master/hardware/arduino/noobtocol.parallel/noobtocol.parallel.ino and it is basically a bridge between the PC and the ch376s. Thus openMSX will open the serial port send some bytes and the arduino will redirect them to ch376s, get the answer if any and send it to the PC.

You may probably need to change the pins and below I show you the ones I used. I recommend you not to use pin 13 (LED pin) because it can cause problems. D0 is pin 5, D1 pin 6 and so on ...
```
//CH376 pins to Arduino digital connections mapping
const int CH_WR = 4;
const int CH_RD = 3;
const int CH_PCS = A0;
const int CH_A0 = A5;
const int CH_INT = 2;
const int CH_D0 = 5;
//CH_Dx = CH_D0 + x
```

Now flash the arduino and we are going to check the skecth with this tool https://github.com/S0urceror/MSX-USB/blob/master/test/usb_via_arduino/src/main.parallel.cpp

If you are in linux you need to add ```#include <assert.h>``` and remove ```-stdlib=libc++``` from the Makefile (https://stackoverflow.com/questions/19774778/when-is-it-necessary-to-use-the-flag-stdlib-libstdc)
Compile this tool ```make main_parallel``` and run it like ``` parallel /dev/ttyUSB0``` (of course change it according to your device)

If everything is ok you will see readData is getting values
```
$ ../dist/main_parallel /dev/ttyUSB0  | more
12:02:48:0001 writeCommand (CH_CMD_RESET_ALL) 0x05
12:02:48:0100 writeCommand (CH_CMD_CHECK_EXIST) 0x06
writeData (0xbe)
0x41 = readData ()
...
```

If this works openMSX will be able to talk to the ch376s, isn't that amazing?

# Compiling openMSX
In order to use ch376s you will need S0urceror's fork of OpenMSX which you can get at https://github.com/S0urceror/openMSX
```
git clone https://github.com/S0urceror/openMSX
```
Then ```./configure```
and if everything went well (you have all the libraries requiered) you should see something like this

```
$ ./configure 
Using Python: python3
Probing target system...
Up to date: derived/x86_64-linux-opt/config/probed_defs.mk
Up to date: derived/x86_64-linux-opt/config/systemfuncs.hh

Found libraries:
  ALSA:             version 1.2.2
  GLEW:             version unknown
  libogg:           version unknown
  libpng:           version 1.6.37
  libtheora:        version unknown
  libvorbis:        version unknown
  OpenGL:           version 4.6
  SDL2:             version 2.0.10
  SDL2_ttf:         version 2.0.15
  Tcl:              version 8.6.10
  zlib:             version 1.2.11

Components overview:
  Emulation core:   yes
  GL renderer:      yes
  Laserdisc:        yes
  ALSA MIDI:        yes

Customisable options:
  Install to        /opt/openMSX
  (you can edit these in build/custom.mk)

All required and optional components can be built.

If the detected libraries differ from what you think is installed on this system, please check the log file: derived/x86_64-linux-opt/config/probe.log
```

If some libraries are not found or installed they will be reported and you can also have a look at  derived/x86_64-linux-opt/config/probe.log for details.

In particular, under Ubuntu 20.04 I had to install these packages but you may need to install additional ones. In such a case, please report.

```
sudo apt-get install libasound2-dev libglew-dev libogg-dev libtheora-dev libvorbis-dev libsdl2-dev libsdl2-ttf-dev tcl-dev zlib1g-dev
```

Next step is to compile the sources ```make -j 8``` and after some minutes and if everything went file you will have a fresh compilation. Then ```sudo make install``` and you are done.

```
$ sudo make install
Using Python: python3
Build configuration:
  Platform: x86_64-linux
  Flavour:  opt
  Compiler: g++
  Subset:   full build
Up to date: derived/x86_64-linux-opt/config/Version.ii
Installing openMSX:
  Executable...
  Data files...
  Documentation...
  C-BIOS...
  Creating symlinks...
Installation complete... have fun!
Notice: if you want to emulate real MSX systems and not only the free C-BIOS machines, put the system ROMs in one of the following directories: /opt/openMSX/share/systemroms or ~/.openMSX/share/systemroms
If you want openMSX to find MSX software referred to from replays or savestates you get from your friends, copy that MSX software to /opt/openMSX/share/software or ~/.openMSX/share/software
```

Now it is time to set up your machine. You will need to add the system rom to /opt/openMSX/share/systemroms or ~/.openMSX/share/systemroms  
You can find get from Fusion-C project https://github.com/ericb59/Fusion-C-v1.2/tree/master/Working%20Folder/Tools/_For%20OpenMSX/systemroms and in particular I will use https://github.com/ericb59/Fusion-C-v1.2/blob/master/Working%20Folder/Tools/_For%20OpenMSX/systemroms/machines/philips/vg8020_basic-bios1.rom
You can also find other roms at https://www.planetemu.net/rom/msx-bios/ 

Now copy the .xml machine description to your your local configuration 
```
cp  /opt/openMSX/share/machines/Philips_VG_8020.xml ~/.openMSX/share/machines/Philips_VG_8020_MSXUSB.xml
```
Open the file .xml and include the ch376s device by addind the following lines in the ```<devices>...</devices>``` section.
```
<CH376s id="ch376s">
      <io base="0x10" num="1" type="IO"/>
      <io base="0x11" num="1" type="IO"/>
</CH376s>
```

**Warning:** If you modify the files in /opt/openMSX/share/machines/ and you recompile and install (make install) your modifications will be lost, that's why it is better to use ~/.openMSX/share/.

Also make sure the rom file is found, maybe you need to check the rom section. Here is how it looks for VG8020 and you should provide vg8020_basic-bios1.rom on r ~/.openMSX/share/systemroms
```
<primary slot="0">
      <ROM id="MSX BIOS with BASIC ROM">
        <rom>
          <filename>vg8020_basic-bios1.rom</filename>
          <sha1>829c00c3114f25b3dae5157c0a238b52a3ac37db</sha1>
        </rom>
        <mem base="0x0000" size="0x8000"/>
      </ROM>
    </primary>
```

As a default, the serial device is located at /dev/tty.usbmodem123451 and you can of course change it in the source code but you can also do a symbolic link ``` sudo ln -s ttyUSB0 /dev/tty.usbmodem123451``` . If your arduino takes other port, like ttyACM0, just change it.

And we have everything needed, now it is time to test it, just type:
 ```
$ openmsx -machine Philips_VG_8020_MSXUSB -carta nextor.rom
```

If there are problems to open the port you will get this message, otherwise port will be found.
 ```
$ openmsx -machine Philips_VG_8020_MSXUSB -carta nextor.rom
failed to open port
```

If everything is ok you will see sth like
```
$ openmsx -machine Philips_VG_8020_MSXUSB -carta ../MSX-USB/drivers/MsxUsbNext/msx/dist/nextor.rom 
writeCommand (CH_CMD_RESET_ALL) 0x05
writeCommand (CH_CMD_CHECK_EXIST) 0x06
writeData (0xbe)
0x41 = readData ()
```

If it hangs in readData that usually means pin definition or connections in the Arduino are not ok. Also it can be some problems with the usb port.

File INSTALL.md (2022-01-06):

# MSX-USB
## Installation instructions
You have to flash a new NEXTOR ROM image onto a MSX flash cartridge. The RookieDrive and other MSX USB initiatives have both Flash and the USB part combined in one cartridge so thats easy. In my prototype setup I have one cartridge with MSX USB and one modded SCC cartridge with flash and that works as well.

You can use the MSX USB cartridge in two modes.

### Use as disk drive
* Download [this](https://github.com/S0urceror/MSX-USB/raw/master/drivers/NextorUsbHost/dist/nextor.rom) ROM image
* Flash the image
* Reboot

The first time you need to boot up with a floppy disk with the NEXTOR.SYS and COMMAND2.COM files. 
Please insert a FAT16 formatted USB Flash Disk in the MSX USB cartridge.
Put NEXTOR.SYS and COMMAND2.COM in the root of that disk. Insert into the MSX and go.

*N.B. if you want to use MSXUSB on the [RookieDrive](http://rookiedrive.com/en/) please use [this](https://github.com/S0urceror/MSX-USB/raw/master/drivers/NextorUsbHost/dist/nextorrd.rom) version of the ROM.*

### Multi purpose USB port
The ROM image now also contains an UNAPI compatible USB Host driver.

You can do the following things:
* [APILIST.COM](https://github.com/S0urceror/MSX-USB/raw/master/drivers/UsbEthernet/dist/apilist.com) MSXUSB to check that the UNAPI driver is ready and works.
* [LSUSB.COM](https://github.com/S0urceror/MSX-USB/raw/master/drivers/UsbEthernet/dist/lsusb.com) to list all technical USB information from the connected USB device.
* [USBETHER.COM](https://github.com/S0urceror/MSX-USB/blob/master/drivers/UsbEthernet/dist/usbether.com) to install the USB Ethernet Driver. You can then subsequently run `INL i` to install Internestor Lite. When all goes well you can then run any TCP/IP applications like `TELNET`, `HUB`, `HGET`, `TFTP`, etc. More information about this you can find on [Konamiman's](https://www.konamiman.com/msx/msx-e.html#inl2) website.
* BLOAD ("[USBKEYBD.BIN](https://github.com/S0urceror/MSX-USB/raw/master/drivers/UsbKeyboard/dist/usbkeybd.bin)"),R to install the USB HID Keyboard driver. This will enable any connected USB HID compliant keyboard.

## Flashing the image
To flash the ROM's you need an appropriate flashing tool. For this I created a program called Flash. You can download it [here](https://github.com/S0urceror/MSX-USB/raw/master/software/dist/flash.com)

It is simple to use Flash. The following statement automatically finds the (mega-)flash cartridge and flashes image.rom.

`FLASH nextor.rom`

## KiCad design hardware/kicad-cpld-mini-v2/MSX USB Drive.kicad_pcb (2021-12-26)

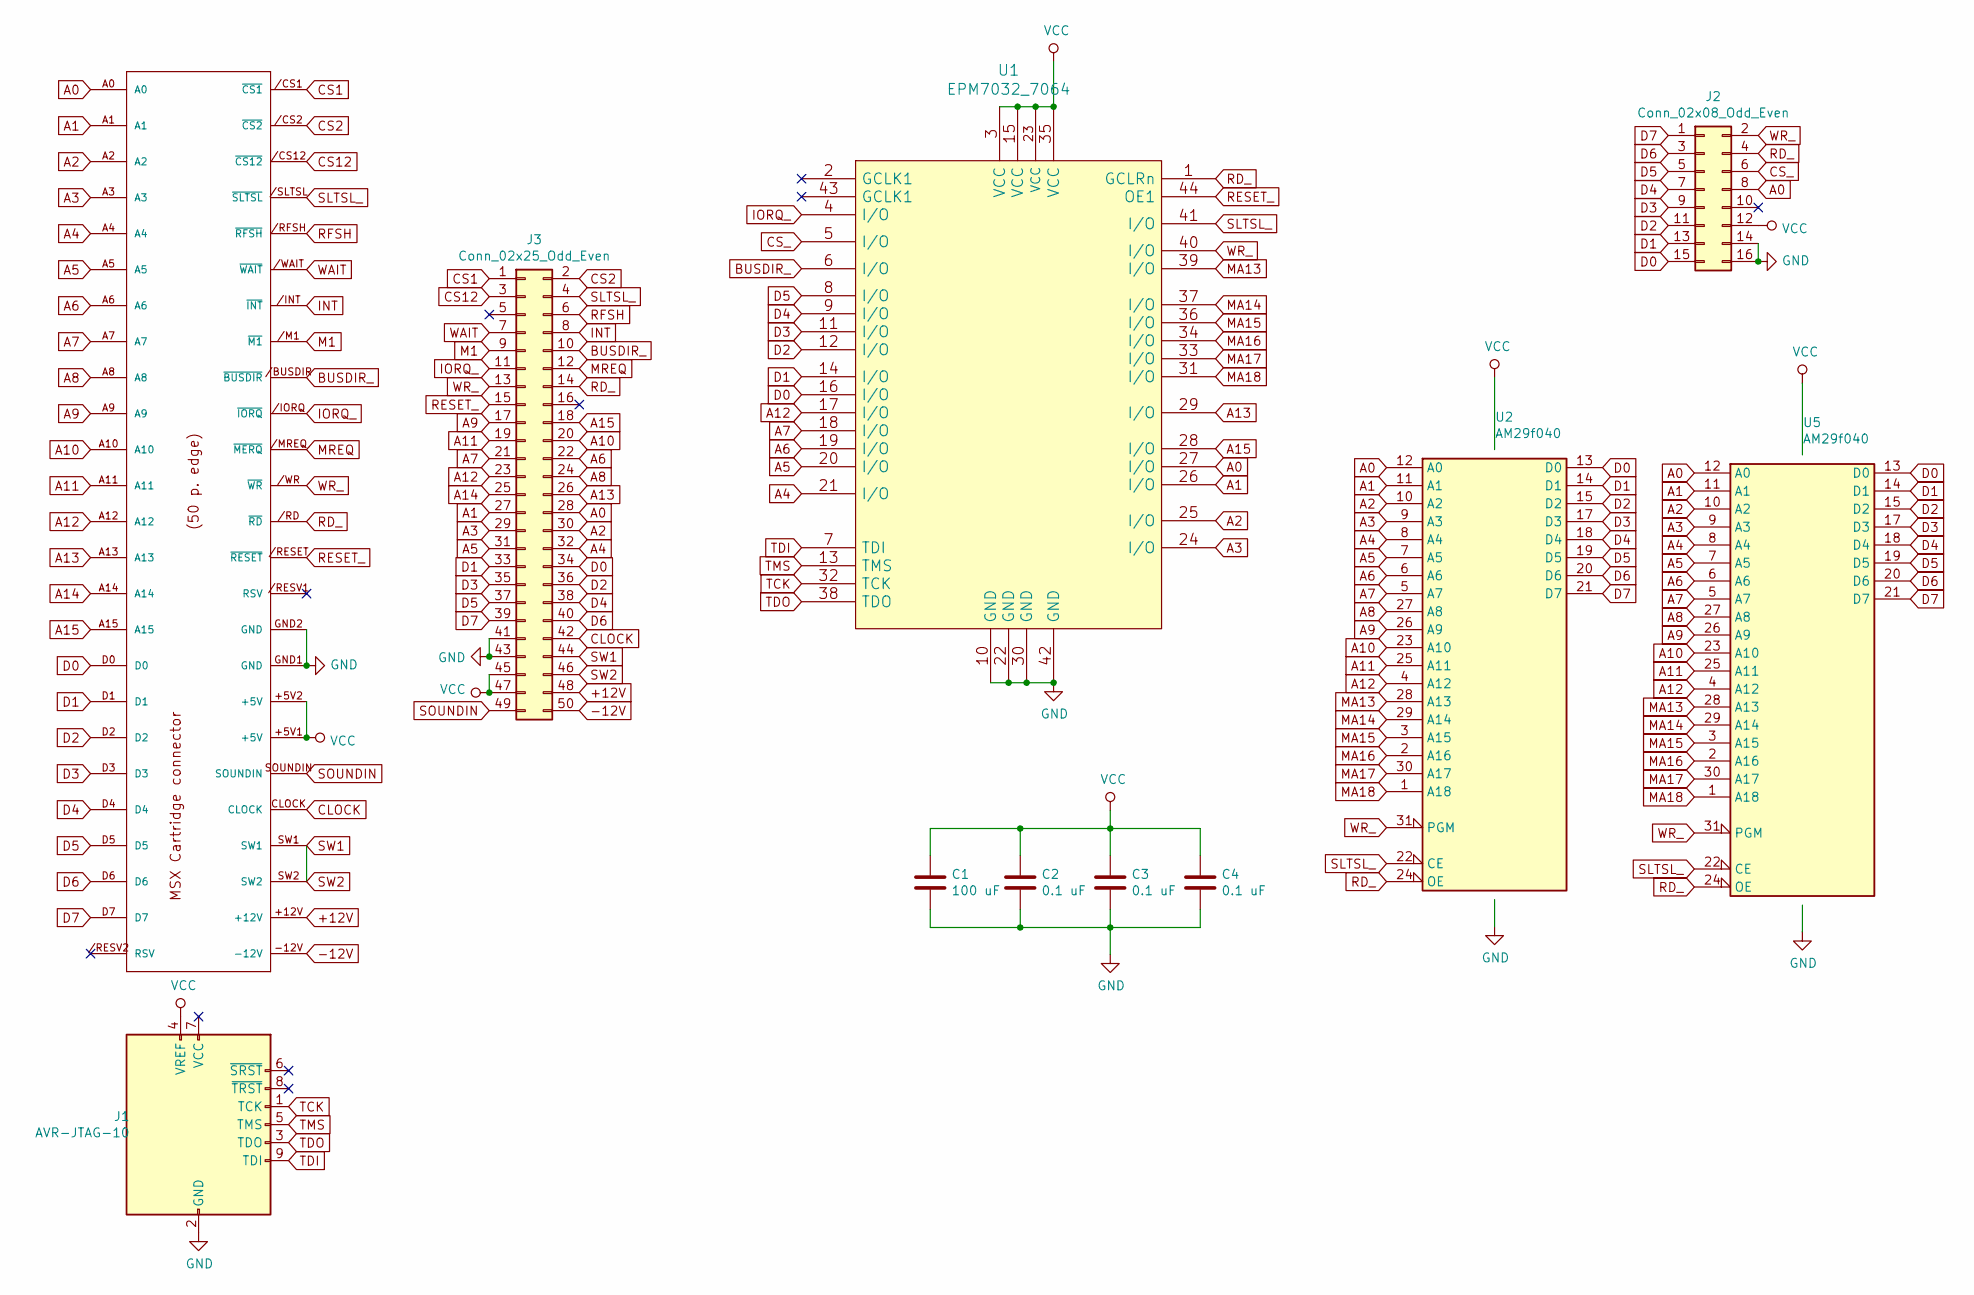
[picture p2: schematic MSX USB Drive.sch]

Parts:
C1: 100 uF; CP_Radial_D5.0mm_P2.50mm
C2, C3, C4: 0.1 uF; C_0805_2012Metric_Pad1.15x1.40mm_HandSolder
EDG1: MSX_CON; msx-con-MSXCART
J1: AVR-JTAG-10; PinHeader_2x05_P2.54mm_Vertical
J2: Conn_02x08_Odd_Even; PinHeader_2x08_P2.54mm_Vertical
J3: Conn_02x25_Odd_Even; PinHeader_2x25_P2.54mm_Vertical
U1: EPM7032_7064; PLCC44
U2: AM29f040; DIP-32_W15.24mm_Socket
U5: AM29f040; PLCC-32_THT-Socket

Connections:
+12V: EDG1.+12V, J3.48
-12V: EDG1.-12V, J3.50
A0: EDG1.A0, J2.8, J3.28, U1.27 (I/O), U2.12 (A0), U5.12 (A0)
A1: EDG1.A1, J3.27, U1.26 (I/O), U2.11 (A1), U5.11 (A1)
A2: EDG1.A2, J3.30, U1.25 (I/O), U2.10 (A2), U5.10 (A2)
A3: EDG1.A3, J3.29, U1.24 (I/O), U2.9 (A3), U5.9 (A3)
A4: EDG1.A4, J3.32, U1.21 (I/O), U2.8 (A4), U5.8 (A4)
A5: EDG1.A5, J3.31, U1.20 (I/O), U2.7 (A5), U5.7 (A5)
A6: EDG1.A6, J3.22, U1.19 (I/O), U2.6 (A6), U5.6 (A6)
A7: EDG1.A7, J3.21, U1.18 (I/O), U2.5 (A7), U5.5 (A7)
A8: EDG1.A8, J3.24, U2.27 (A8), U5.27 (A8)
A9: EDG1.A9, J3.17, U2.26 (A9), U5.26 (A9)
A10: EDG1.A10, J3.20, U2.23 (A10), U5.23 (A10)
A11: EDG1.A11, J3.19, U2.25 (A11), U5.25 (A11)
A12: EDG1.A12, J3.23, U1.17 (I/O), U2.4 (A12), U5.4 (A12)
A13: EDG1.A13, J3.26, U1.29 (I/O)
A14: EDG1.A14, J3.25
A15: EDG1.A15, J3.18, U1.28 (I/O)
BUSDIR_: EDG1./BUSDIR (~BUSDIR), J3.10, U1.6 (I/O)
CLOCK: EDG1.CLOCK, J3.42
CS1: EDG1./CS1 (~CS1), J3.1
CS2: EDG1./CS2 (~CS2), J3.2
CS12: EDG1./CS12 (~CS12), J3.3
CS_: J2.6, U1.5 (I/O)
D0: EDG1.D0, J2.15, J3.34, U1.16 (I/O), U2.13 (D0), U5.13 (D0)
D1: EDG1.D1, J2.13, J3.33, U1.14 (I/O), U2.14 (D1), U5.14 (D1)
D2: EDG1.D2, J2.11, J3.36, U1.12 (I/O), U2.15 (D2), U5.15 (D2)
D3: EDG1.D3, J2.9, J3.35, U1.11 (I/O), U2.17 (D3), U5.17 (D3)
D4: EDG1.D4, J2.7, J3.38, U1.9 (I/O), U2.18 (D4), U5.18 (D4)
D5: EDG1.D5, J2.5, J3.37, U1.8 (I/O), U2.19 (D5), U5.19 (D5)
D6: EDG1.D6, J2.3, J3.40, U2.20 (D6), U5.20 (D6)
D7: EDG1.D7, J2.1, J3.39, U2.21 (D7), U5.21 (D7)
GND: C1.2, C2.2, C3.2, C4.2, EDG1.GND1 (GND), EDG1.GND2 (GND), J1.2 (GND), J1.10 (GND), J2.14, J2.16, J3.41, J3.43, U1.10 (GND), U1.22 (GND), U1.30 (GND), U1.42 (GND), U2.16 (GND), U5.16 (GND)
INT: EDG1./INT (~INT), J3.8
IORQ_: EDG1./IORQ (~IORQ), J3.11, U1.4 (I/O)
M1: EDG1./M1 (~M1), J3.9
MA13: U1.39 (I/O), U2.28 (A13), U5.28 (A13)
MA14: U1.37 (I/O), U2.29 (A14), U5.29 (A14)
MA15: U1.36 (I/O), U2.3 (A15), U5.3 (A15)
MA16: U1.34 (I/O), U2.2 (A16), U5.2 (A16)
MA17: U1.33 (I/O), U2.30 (A17), U5.30 (A17)
MA18: U1.31 (I/O), U2.1 (A18), U5.1 (A18)
MREQ: EDG1./MREQ (~MERQ), J3.12
RD_: EDG1./RD (~RD), J2.4, J3.14, U1.1 (GCLRn), U2.24 (OE), U5.24 (OE)
RESET_: EDG1./RESET (~RESET), J3.15, U1.44 (OE1)
RFSH: EDG1./RFSH (~RFSH), J3.6
SLTSL_: EDG1./SLTSL (~SLTSL), J3.4, U1.41 (I/O), U2.22 (CE), U5.22 (CE)
SOUNDIN: EDG1.SOUNDIN, J3.49
SW1: EDG1.SW1, EDG1.SW2, J3.44, J3.46
TCK: J1.1 (TCK), U1.32 (TCK)
TDI: J1.9 (TDI), U1.7 (TDI)
TDO: J1.3 (TDO), U1.38 (TDO)
TMS: J1.5 (TMS), U1.13 (TMS)
VCC: C1.1, C2.1, C3.1, C4.1, EDG1.+5V1 (+5V), EDG1.+5V2 (+5V), J1.4 (VREF), J2.12, J3.45, J3.47, U1.3 (VCC), U1.15 (VCC), U1.23 (VCC), U1.35 (VCC), U2.32 (VCC), U5.32 (VCC)
WAIT: EDG1./WAIT (~WAIT), J3.7
WR_: EDG1./WR (~WR), J2.2, J3.13, U1.40 (I/O), U2.31 (PGM), U5.31 (PGM)

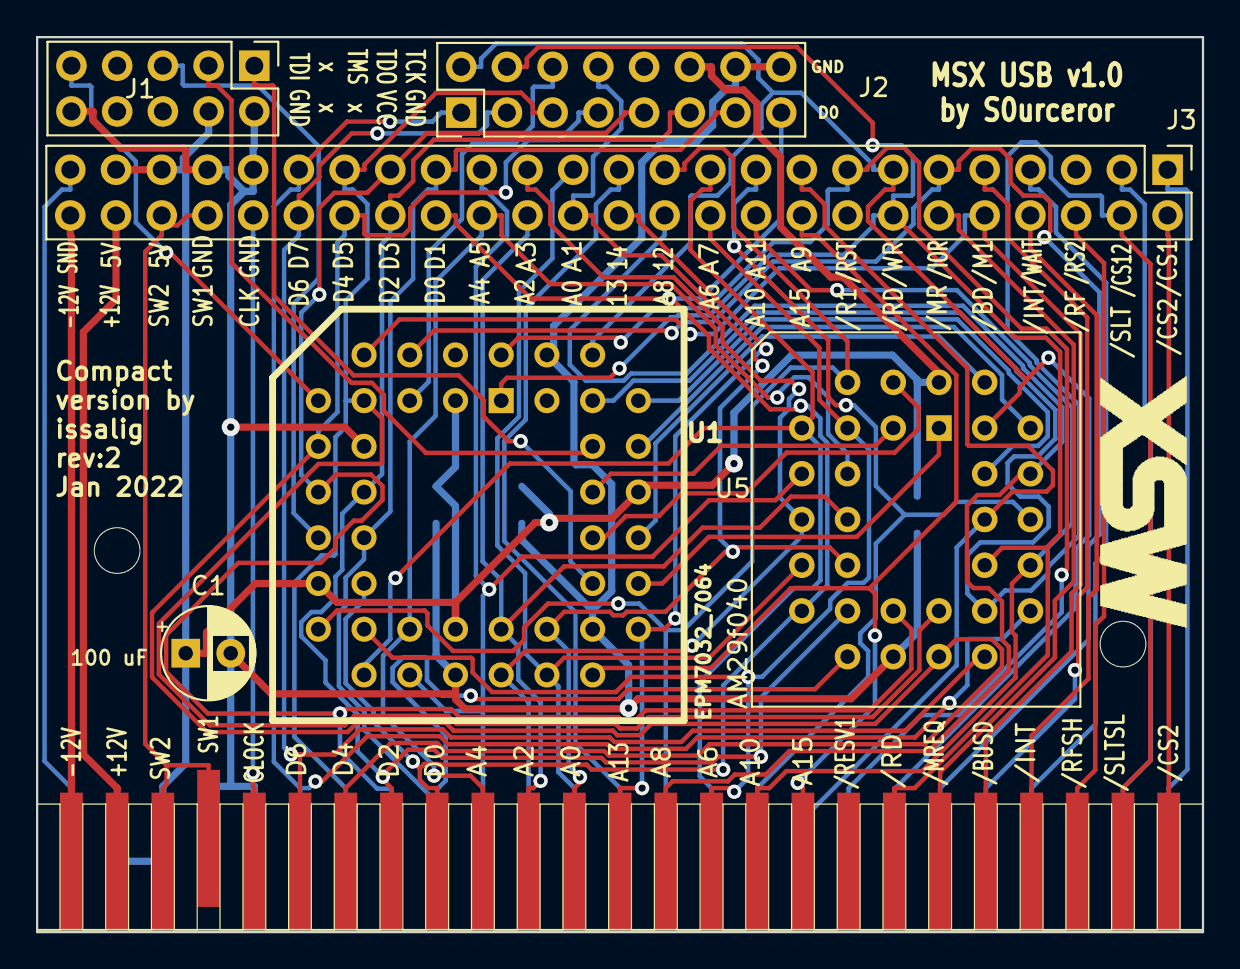
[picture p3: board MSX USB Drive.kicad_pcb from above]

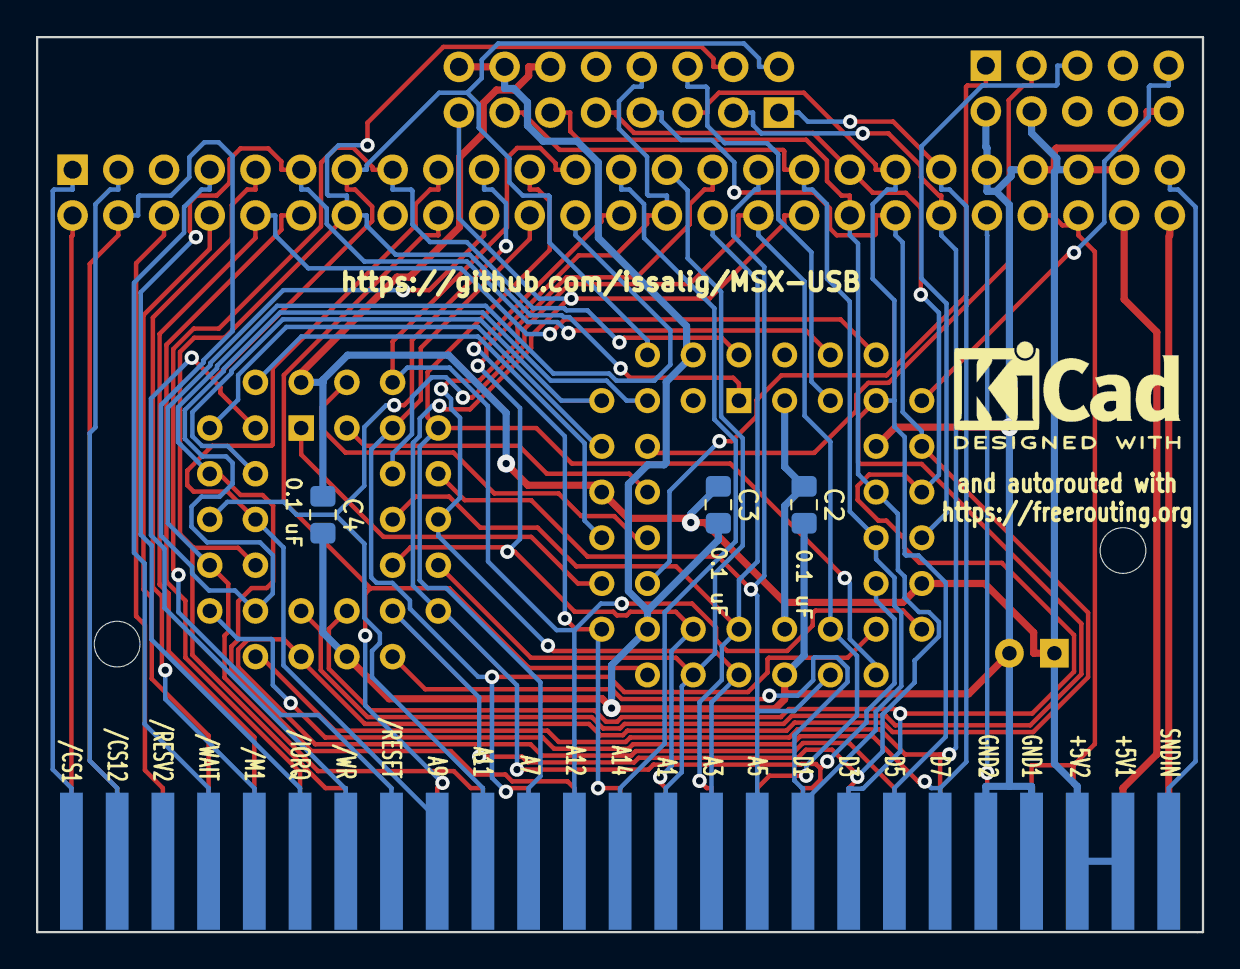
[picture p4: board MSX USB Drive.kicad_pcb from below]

Board: 2 copper layers, 64.8 x 49.7 mm, 11 parts (3 on the bottom side), 56 nets.

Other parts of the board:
LOGO_MSX: LOGO_MSX

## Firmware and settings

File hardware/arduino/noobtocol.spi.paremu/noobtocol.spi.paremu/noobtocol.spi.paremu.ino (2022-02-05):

#include <SPI.h>

#define CH376_CMD_GET_IC_VER      0x01
#define CH_CMD_ENTER_SLEEP        0x03
#define CH375_CMD_RESET_ALL       0x05
#define CH375_CMD_CHECK_EXIST     0x06
#define CH375_CMD_SET_USB_ADDR    0x13
#define CH375_CMD_SET_USB_MODE    0x15
#define CH_CMD_SET_EP0_RX         0x18
#define CH_CMD_SET_EP0_TX         0x19
#define CH_CMD_SET_EP1_RX         0x1a
#define CH_CMD_SET_EP1_TX         0x1b
#define CH_CMD_SET_EP2_RX         0x1c
#define CH_CMD_SET_EP2_TX         0x1d
#define CH375_CMD_GET_STATUS      0x22
#define CH375_CMD_UNLOCK_USB      0x23
#define CH375_CMD_RD_USB_DATA     0x27
#define CH375_CMD_RD_USB_DATA_UNLOCK     0x28
#define CH_CMD_WR_EP0             0x29 // DATA3
#define CH_CMD_WR_EP1             0x2A // DATA5
#define CH_CMD_WR_EP2             0x2B // DATA7
#define CH375_CMD_WR_HOST_DATA    0x2C
#define CH376_CMD_CLR_STALL       0x41
#define CH375_CMD_ISSUE_TKN_X     0x4E
#define CH_CMD_SET_REGISTER       0x0b
#define CH_CMD_GET_REGISTER       0x0a
#define CH_CMD_DELAY_100US        0x0f
#define CH375_CMD_GET_DESCR       0x46
#define CH_CMD_TEST_CONNECT       0x16
#define CH_CMD_SET_FILE_NAME      0x2f
#define CH_CMD_DISK_CONNECT       0x30
#define CH_CMD_DISK_MOUNT         0x31
#define CH_CMD_FILE_OPEN          0x32
#define CH_CMD_FILE_CLOSE         0x36
#define CH_CMD_FILE_ENUM_GO       0x33
#define CH_CMD_BYTE_READ          0x3a
#define CH_CMD_BYTE_RD_GO         0x3b
#define CH_CMD_BYTE_WRITE         0x3c
#define CH_CMD_BYTE_WR_GO         0x3d
#define CH_CMD_DIR_CREATE         0x40
#define CH_CMD_FILE_CREATE        0x34
#define CH_CMD_WR_REQ_DATA        0x2d
#define CH_CMD_DIR_INFO_READ      0x37
#define CH_CMD_BYTE_LOCATE        0x39
#define CH_CMD_FILE_ERASE         0x35

// return codes
#define CH_ST_RET_SUCCESS         0x51
#define CH_ST_RET_ABORT           0x5F

int ledPin = 11;
int intPin = 5;
int misoPin = 3;

int bytes_following;
bool extended_command;
bool zero_ended_command;
bool wait_for_operation_status;
//bool cmd_get_status;
//uint8_t lastStatus;

void setup() {
  // initialize SPI pins
  pinMode(SS, OUTPUT);
  digitalWrite(SS, HIGH);
  SPI.begin ();
  
  // initialize Teensy USB serial
  Serial.begin(0); // baudrate is always maximum usb bus speed 12Mbit/sec

  // initialize LED
  pinMode (ledPin,OUTPUT);
  digitalWrite (ledPin, LOW);

  //lastStatus = 0xff;
}


void beginCmd (byte cmd)
{
  extended_command = false;
  zero_ended_command = false;
  wait_for_operation_status = false;
  //cmd_get_status = false;
  
  switch (cmd) 
  {
    case CH_CMD_ENTER_SLEEP:        bytes_following = 1;
                                    break;   
    case CH375_CMD_CHECK_EXIST:     bytes_following = 3;
                                    break;
    case CH375_CMD_SET_USB_MODE:    wait_for_operation_status = true;
                                    break;
    case CH375_CMD_SET_USB_ADDR:    bytes_following = 2;
                                    break;
    case CH375_CMD_WR_HOST_DATA:    bytes_following = 2;
                                    extended_command = true;
                                    break; 
    case CH_CMD_SET_EP0_RX:         bytes_following = 2;
                                    break;
    case CH_CMD_SET_EP0_TX:         bytes_following = 2;
                                    break;
    case CH_CMD_SET_EP1_RX:         bytes_following = 2;
                                    break;
    case CH_CMD_SET_EP1_TX:         bytes_following = 2;
                                    break;
    case CH_CMD_SET_EP2_RX:         bytes_following = 2;
                                    break;
    case CH_CMD_SET_EP2_TX:         bytes_following = 2;
                                    break;
    case CH_CMD_WR_EP0:             bytes_following = 2;
                                    extended_command = true;
                                    break;  
    case CH_CMD_WR_EP1:             bytes_following = 2;
                                    extended_command = true;
                                    break;  
    case CH_CMD_WR_EP2:             bytes_following = 2;
                                    extended_command = true;
                                    break;                                                                                            
    case CH375_CMD_GET_STATUS:      bytes_following = 2;
                                    //cmd_get_status = true;
                                    break; 
    case CH375_CMD_ISSUE_TKN_X:     bytes_following = 3;
                                    break;           
    case CH376_CMD_GET_IC_VER:      bytes_following = 2;
                                    break;
    case CH376_CMD_CLR_STALL:       bytes_following = 2;
                                    break;
    case CH375_CMD_RD_USB_DATA:     bytes_following = 2;
                                    extended_command = true;
                                    break;
    case CH375_CMD_RD_USB_DATA_UNLOCK:     
                                    bytes_following = 2;
                                    extended_command = true;
                                    break;
    case CH_CMD_SET_REGISTER:       bytes_following = 3;
                                    break;
    case CH_CMD_GET_REGISTER:       bytes_following = 3;
                                    break;        
    case CH_CMD_DELAY_100US:        bytes_following = 2;
                                    break;
    case CH375_CMD_GET_DESCR:       bytes_following = 2;
                                    break;         
    case CH_CMD_TEST_CONNECT:       bytes_following = 2;
                                    break;   
    case CH_CMD_DISK_CONNECT:       bytes_following = 1;
                                    break;   
    case CH_CMD_DISK_MOUNT:         bytes_following = 1;
                                    break;    
    case CH_CMD_FILE_OPEN:          bytes_following = 1;  
                                    break;          
    case CH_CMD_FILE_CLOSE:         bytes_following = 2;  
                                    break;          
    case CH_CMD_FILE_ENUM_GO:       bytes_following = 1;  
                                    break;    
    case CH_CMD_FILE_ERASE:         bytes_following = 1;  
                                    break;                                                                   
    case CH_CMD_SET_FILE_NAME:      bytes_following = 15;
                                    zero_ended_command = true;
                                    break;         
    case CH_CMD_BYTE_READ:          bytes_following = 3;
                                    break;      
    case CH_CMD_BYTE_RD_GO:         bytes_following = 1;
                                    break;  
    case CH_CMD_BYTE_WRITE:         bytes_following = 3;
                                    break;
    case CH_CMD_BYTE_WR_GO:         bytes_following = 1;
                                    break;       
    case CH_CMD_DIR_CREATE:         bytes_following = 1;
                                    break;  
    case CH_CMD_FILE_CREATE:        bytes_following = 1;
                                    break;            
    case CH_CMD_WR_REQ_DATA:        bytes_following = 2;
                                    extended_command = true;
                                    break;         
    case CH_CMD_DIR_INFO_READ:      bytes_following = 2;
                                    break;         
    case CH_CMD_BYTE_LOCATE:        bytes_following = 5;
                                    break;                
    case CH375_CMD_UNLOCK_USB:      bytes_following = 1;
                                    break;                                                                                                                                                                                                                       
    default:                        bytes_following = 1;  
                                    break;
  }
  digitalWrite(SS, LOW);  
  digitalWrite (ledPin, HIGH);
}
void checkEndCmd (byte value)
{
  if (zero_ended_command && value==0)
  {
    bytes_following=0;
    digitalWrite(SS, HIGH);
    digitalWrite (ledPin, LOW);
    return; 
  }
  if (wait_for_operation_status && (value==CH_ST_RET_SUCCESS || value==CH_ST_RET_ABORT))
  {
    bytes_following=0;
    digitalWrite(SS, HIGH);
    digitalWrite (ledPin, LOW);
    return;
  }
  if (--bytes_following==0) 
  {
      if (extended_command)
      {
        extended_command = false;
        bytes_following = value;
        if (bytes_following>0)
          return;
      }
      digitalWrite(SS, HIGH);
      digitalWrite (ledPin, LOW);
      return;
  }
}

void writeCommand (byte cmd)
{
  beginCmd (cmd);
  SPI.transfer (cmd);
  checkEndCmd (-1);
}

void writeData (byte data)
{
  SPI.transfer (data);
  checkEndCmd (data);
}

byte readData ()
{
  byte data = SPI.transfer (0);
  checkEndCmd (data);
/*
  if (cmd_get_status && lastStatus!=0xff)
  {
    data = lastStatus;
    lastStatus = 0xff;
  }
*/
  return data;
}

byte readStatus () 
{
  byte data;
  data = digitalRead (intPin)<<7; // INT
  //data = digitalRead (misoPin)<<7; // MISO
  data += 1; // simulated READY bit
/*
  if ((data & 0x80) == 0) // interrupt pulls down to zero
  {
    digitalWrite(SS, LOW);
    SPI.transfer (CH375_CMD_GET_STATUS);
    delayMicroseconds (1);
    lastStatus = SPI.transfer (0);
    digitalWrite(SS, HIGH);
  }
  else
    lastStatus = 0xff;
*/    
  return data;
}

void loop() 
{
  byte data;
  int length;
  int i;
  byte *inbytes,*outbytes;

  // loop when no serial request received
  if (Serial.available() == 0) 
    return;

  // process serial request
  data = ReadByteFromSerial();
  switch (data)
  {
  case 1: //Write command
    data = ReadByteFromSerial();
    writeCommand(data);
    break;
  case 2: //Read status
    data = readStatus ();
    WriteByteToSerial(data);
    break;
  case 3: //Write data
    data = ReadByteFromSerial();
    writeData(data);
    break;
  case 4: //Read data
    data = readData();
    WriteByteToSerial(data);
    break;
  case 6: //Read multiple data
    length = ReadByteFromSerial();
    inbytes = (byte*) malloc (length);
    for (i = 0; i < length; i++)
      inbytes[i] = readData();
    Serial.write (inbytes,length);
    Serial.send_now();
    free (inbytes);
    break;
  case 7: //Write multiple data
    length = ReadByteFromSerial();
    outbytes = (byte*) malloc (length);
    for (i = 0; i < length; i++)
    {
      outbytes[i] = ReadByteFromSerial();
      writeData(outbytes[i]);
    }
    free (outbytes);
    break;    
  case 10: // block benchmark
    for (i=0;i<512*10;i++) 
    {
      Serial.write (0xAA);
    }
    break;
  case 11: // roundtrip benchmark
    Serial.write (Serial.read ());
    break;
  default:
    while (Serial.available() >= 0) Serial.read();
  }
}

byte ReadByteFromSerial()
{
   while (Serial.available() == 0);
   return Serial.read();
}

void WriteByteToSerial(byte data)
{
  while (Serial.availableForWrite() == 0);
  Serial.write(data);
}
